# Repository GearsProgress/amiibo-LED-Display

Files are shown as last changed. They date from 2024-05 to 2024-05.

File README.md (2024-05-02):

# amiibo LED Display

This repository serves as documentation and storage for the UW-Stout Capstone project created by Dylan Robens, Austin Weber, Joaquin Sabin, and Alex Schroeder.

These files are provided as is and with no liability, however they are free to be used to recreate the project.

This repository is not meant to be a tutorial, but everything you would need to recreate the project should be documented. If you have any questions, feel free to reach out!



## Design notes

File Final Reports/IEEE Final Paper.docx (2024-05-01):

Joaquin Sabin, Dylan Robens, Austin Weber, Alex Schroeder, Member, IEEE

# I. INTRODUCTION

This project overviews the subject of Near Field Communication (NFC) by exploring the basics of how NFC communicates and transfers data. It also focuses on how to design a Near Field Communication antenna. The can communicate with passive NFC tags at a practical distance without any noise or excess data interfering with the communication. It then applies the antenna design work by fabricating a custom printed circuit board so that it can be used in the real world and tested in real world scenarios.

The method of showcasing that the antenna is working and functioning as intended is demonstrated with Nintendo’s amiibo figurines that will be used as the communication device for ensuring that the data transfer is working. amiibo are little figures from Nintendo that contain NFC chips (NTAG215) inside them. These chips store tons of data for multiple different games which makes them perfect candidates to see if the antenna is able to accurately transfer data at a fast rate.

# II. Design Problems and Objectives

The goal for the PCB design element of this project was to create a custom PCB with an integrated NFC antenna that is capable of longer-than-average-range data transfer and support power modularity with each antenna. The NFC readers will interface with a ATMega2560 microprocessor, common cathode multicolored LED lights, power supply, and power transfer nodes. All these elements, combined with a custom shelf-like housing designed and built using a 3D printer, can come together and create a display shelf that scans NFC based collectable figurines and changes the colors of the LED lights accordingly. This will have required multiple iterations of custom PCBs, custom programming, and many iterations of 3D modeling work.

The NFC based collectable figures being used are Nintendo’s amiibo. The reasoning behind using amiibo is for safety and security reasons. The antennas were not designed to enable the ability to collect private or secure data from other NFC chips, such as credit cards, key fobs, and security devices. The amiibo figurines feature an NTAG215 NFC chip that stores game data unique to each figure. This unique data will be used to determine what figure was being scanned, which will then be compared to a database that will return the correct color of lighting for that specific figure.

# III. Detailed Design Documentation

The project had started with some general ideas and took some time to finalize what exactly it will be. It was decided that creating a display case with the ability to scan figures while also displaying them in a unique way within the case would be a nice concept. The group agreed on this idea and wanted to figure out how to incorporate electrical engineering concepts into a project like this, and the group hadn’t made any custom PCBs without guidance before, so wanted to learn how. It was decided to go with a box design that can house 3 figures at once and is made up of white plastic with a gray outer shell. The main reasons for going for a two-tone design is that it is more visually appealing, and the gray PLA stops light diffusion easily compared to white PLA. This way light will bleed through where intended, and not bleed where it is not intended.

When a figure is scanned, it’s unique figure data from the NFC tag hidden inside of it will be used to light up an LED which has the same color scheme as the figure. There are many ways you can use NFC technology and data depending on the type of chip you are scanning and the application. The antenna will not be able to be used to scan credit card data and personal safety devices. This design choice was done to ensure the project cannot be used in any malicious ways. Showing corresponding LEDs lighting up was decided to be a simple and useful method of displaying to the user that the NFC data is being read. The easiest way to utilize NFC data communication will be to use a multicolor LED, and light it up according to the ID scanned. Between the 2 types of LED lights, (common cathode and a common anode) it was determined a common cathode would be the best to use as it will be easier to supply different voltages to the RGB LED.

The data from the amiibo will be read through wireless data transfer as long as it is within range of an NFC antenna. Researching how NFC antennas work was the main focus of the design from the first semester. The CLRC663 chip was decided to be the best use for the antenna as it is specifically for reading and processing data being received from an NFC antenna. Incorporating this chip into the custom PCB required a dive into the schematics of the chip to find out how the CLRC663 operates.

Early Conceptual Stages of the Custom PCB:

The project originally involved a single board with three built in NFC antennas to read data from the NFC chips that were placed on them. This was done for simplicity of manufacturing down the road, but led to being too risky for the project in its current state if the board resulted in not working.

The project was redone as a separate NFC antenna board, combined with a custom-made motherboard designed from Arduino Mega 2560 schematics. This was done to allow modularity for the final product and allow the ability to switch out multiple revisions of NFC antenna boards as new designs were made. Having this capability allowed easier access to testing designs as they came in and more adaptability down the road.

An RC522 chip was originally featured on the NFC antenna PCB but later changed as the RC522 is no longer available. Later this was switched out to the CLRC663 due to part availability and future compatibility with other components. Due this chip being relatively new, public documentation, code, and forum posts were not widely available and led to project delays that affected the end product.

Antenna Design Calculations:

After figuring out the design and goals of the project, the next step was to decide on the layout of the antenna PCB. The first step was the general layout. To achieve this, a few days were spent specifying the parameters of the antenna. It was important to know what needed to be scanned in the first place. To get data transferred from the NFC tag to the NFC antenna it was important to know what frequency the NFC tag from the amiibo figure could operate at. Datasheets showed that the figure has an NTAG215 chip inside of it which is able to transfer data at a frequency of 13.56Mhz.

After some research it could be found that an ST25TB or ST25TV series antenna had the required tuning frequency necessary for communicating at 13.56Mhz. Initially it seemed that either the ST25TV or ST25TB could be used but further research showed that the ST25TV series would not work with the NTAG215 chip found in the amiibo figures. From here it was decided to go with the ST25TB series antenna. This provided a great starting point for beginning the antenna calculations.

Deciding on the Shape of the Antenna:

Early design revisions of the NFC antenna board featured multiple versions with different antenna shapes. Research was done to determine the most effective antenna shape for the purpose of the NFC Antenna. It was discovered that a circle design has less data loss, but the square design has more stability. It is for this reason that for the antenna design on the NFC antenna board, a square design with rounded edges was featured as the main antenna. This design incorporates features from both the circular and square design that gives us beneficial traits from both. This design was also chosen due to limitations during board development from the software that was primarily used to design said boards. The simplified geometry allowed for easier calculations of antenna properties during development and led to the development of an accurate Smith Chart to aid in the antenna tuning process down the line.

NFC Antenna Smith Chart

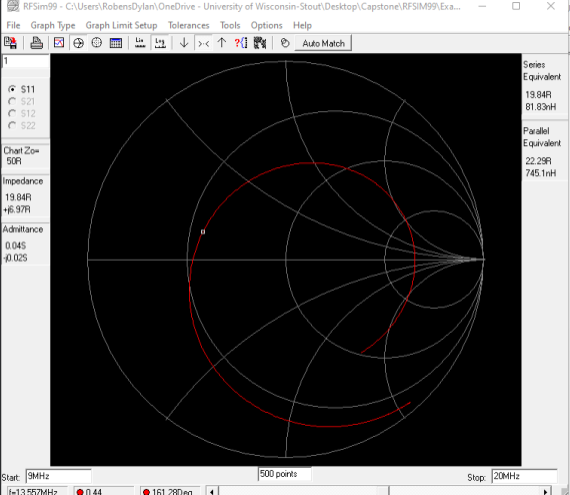
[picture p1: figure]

Finding The Ideal Operating Range/Distance:

NXP, an RFID/NFC antenna design company, features a simulation tool to find the ideal operating range that would be needed. It also provided useful documentation and made it possible to learn what kind of range the antenna could achieve. The notable details learned here were that a 4cm-diameter antenna would allow for an approximately 3cm operating range to scan the NFC tag.

Early Antenna Design Equations and Parameter Calculations:

After the operating range, the shape, and the size of the antenna had been decided, research began to find the necessary equations and information that would be needed in order to calculate the electronic components required for the antenna. Since the EMC filter used for the antenna was static, the matching circuit had to be tuned in the simulation to give the intended result. From here, the next step would be to decide on figuring out the actual antenna-specific values. Research showed that the internal resistance of the coil for the antenna could be found by taking the resistivity of copper, multiplying it by the length of the coil of wire, and dividing it by the cross-sectional area of the overall wire.

After calculating the resistance of the antenna, the inductance of the antenna could be found by using the number of turns, coupling coefficients, resistance of the antenna, and diameter. Once the inductance in the circuit was known it could then be used to find the capacitance. Next, the values were plugged into an online antenna calculator software which was used to double check that all the calculations were accurate and plausible.

NFC Antenna PCB Design:

The resulting design and schematic for the NFC antenna PCB was based on the supplier recommended circuit for the CLRC663 and conventional standards for NFC antenna circuits. 0-ohm resistors were utilized throughout the design to reduce EMI and achieve effective data transmission between the CLRC663 and the main processor unit on the custom motherboard. Additional test pins were added in the design to allow for additional debugging capabilities, should issues arise with the board.

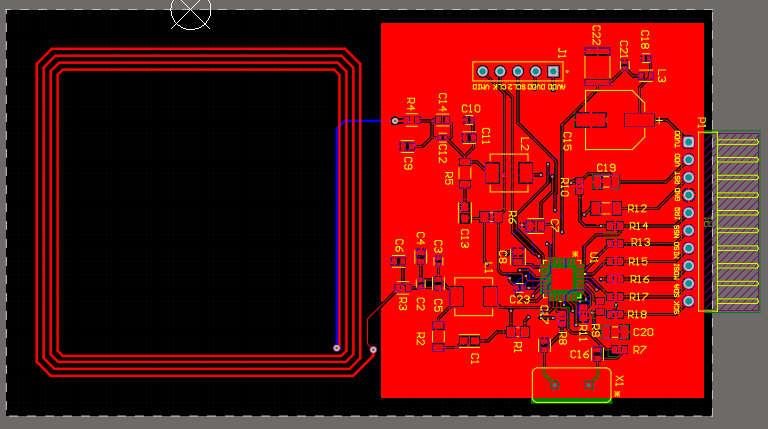
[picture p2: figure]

NFC Antenna Custom PCB Design Schematic

Custom Motherboard PCB Design:

In addition to the antenna, a custom motherboard would be needed to have the logic of the system running on it. It was designed and created using an open-source Arduino 2560 schematic as a reference, only including the aspects that would be relevant to this project’s needs. The main things that were changed about this board are the headers that are being used to interface with the NFC readers, LEDs, and various other electronic devices present within the final design. To reduce the cost of the system overall and increase the amount of available space, unused headers were removed when they were not needed for any devices in the system. The main reasons the custom motherboard was created and used in this project was due to the fact that it would allow for a better use of space and provide the additional memory required to store all the amiibo data. Using these custom boards were beneficial because they have the space efficiency of an Arduino Uno with the memory abilities of an Arduino Mega 2560.

PCB Fabrication

PCB fabrication was done by JLCPCB, a PCB manufacturing company based in China. It was decided that PCB assembly would be completed during the fabrication process, due to the pick and place capabilities that were featured at their facilities and the complex nature of the custom PCB designs. Due to the location of JLCPCB and miscommunication between the design team and the manufacturer, multiple project delays occurred that affected the end product. When globally sourcing the parts from different manufacturers, multiple shipping delays occurred that pushed the timeline of the project back further and led to less time to debug the boards.

This issue was primarily encountered when ordering the first PCB design, which was the NFC antenna board. After having first ordered the parts that would be required for the board, it took over a month for those parts to be shipped to the JLCPCB manufacturing site. This led to parts that were previously in stock at the manufacturing site being out by the time the previously ordered parts arrived. Due to this, many delays were experienced in receiving the NFC antenna boards and as a result there has been less time to test and debug. This issue was also experienced with the custom Arduino Mega Boards that were created, but to a lesser degree due to previous experience with the capabilities of JLCPCB’s stock options.

PCB Fabrication Results

After the custom NFC antenna boards were received, testing immediately began and early testing unfortunately showed that they do not operate as expected. Due to the limited open-source code that is available on the internet for the particular chipset that was used, the boards were not able to function as expected. It was found that its possible to read from the CLRC663 chip on the board. However, the registers from the chip are set with default 1’s and 0’s. In order to program the chip with its intended values, a Clev663BM Programming board would be required to import the program onto our chips. If there was more time to debug these boards and possibly rework the design itself, there could have been a better opportunity to make a immediately functioning board that works as the simulations show they should.

Another large issue was encountered with JLCPCB when the custom motherboard was ordered. JLCPCB incorrectly placed a lot of the IC’s and microchips that were present on the board due to the naming conventions that were used; the manufacturer incorrectly assumed that a lot of the parts had an orientation that did not matter. This led to the board not functioning as expected and being completely unusable with the project. If more time was available, more testing could be done to debug these boards and fix a multitude of the issues that are present.

3D Modeling

While the PCBs were being made in Altium, work also began on the necessary housing in which the NFC antennas would rest in. The plan was for the amiibo figures to have a visually appealing shelf-like housing, so they wouldn’t just be resting on a large PCB with a bunch of wires visible to the user.

The original prototype consisted of 11 individual files that would need to be printed to complete one full shelf. The general concept was that the amiibo were to be a slotted into the shelf and rest in place while lighting up LEDs that would correspond to the data being read from the amiibo. The shelf was also made to be easily constructable by hand without the need for any tools. This was to make disassembly faster in case a shelf had an issue. The shelf parts slid on and off easily and constrained the shelf in a physically secure way.

While printing, some of the parts were extremely thin, which led to warping issues for longer prints. This caused many prints to fail in early design stages. Originally the project was utilizing a personal 3D printer to print the needed parts, but this constrained the timeframe of the project as the prints were inconsistent and took quite a while to print. The group was later informed about the printing lab on campus and all 3D printed parts for capstone were supposed to be printed in the lab. The prints had been changed to be made easier by the time the printing restrictions were introduced, so the design had been refined by removing redundant parts and making existing parts more robust to avoid warping. While printing, the group also encountered some issues with removing supports in very tightly cramped places, so the files were changed to remove any instance that would create supports that were troubling to remove.

The second prototype featured a slot for a photo resistor to activate/deactivate an NFC antenna and a slot for the NFC antenna boards to rest under where the amiibo would sit. After designing this prototype, the final design was fabricated at the print lab and the design was constructed. Testing began after the final design was constructed to test out the capabilities of the NFC antennas in conjunction with the Arduino Mega as well as making sure that everything was functioning as expected. During this phase, minor design adjustments were made to increase the efficiency of the system and ensure that it was as “end-user proof” as possible.

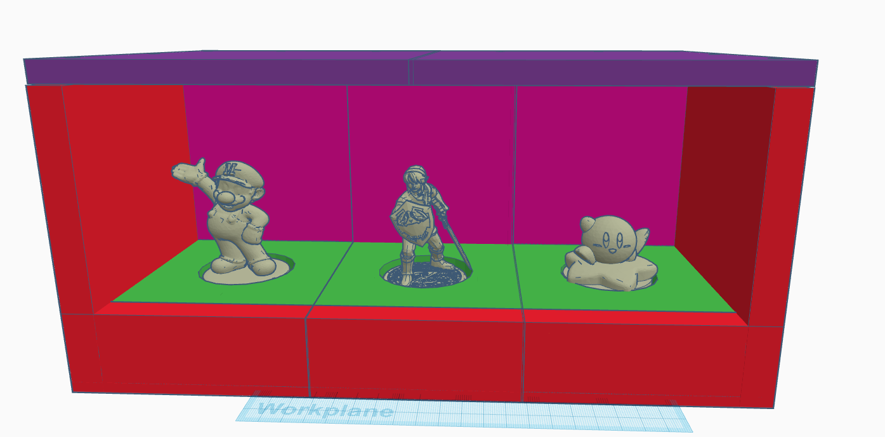
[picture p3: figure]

Arduino Software

During the planning stages for the software, it was determined that storage space would be an issue due to the large number of figurines the software needed to be compatible with. It was also determined early on that an Arduino-based motherboard would be used for the microcontroller to control this entire project, as this was a device that the team had familiarity with. The storage needs required the use of an Arduino Mega, which contains enough storage space for the head, tail, and color values of each figure.

A goal of the software was to split each sensor into its own class. That way, each sensor could be individually tested to make sure it was functioning properly. The program utilizes three main classes: one for the MFRC522 board, one for the photoresistors, and one for the LED logic. The MFRC522 and LED lights that were purchased both had recommended libraries for interacting with them, which assisted in the programming process. This meant that the focus could be on new aspects of the program, rather than learning how each external device functioned. The photoresistor class was custom made, and although simple, was extremely helpful in making the code clean and concise.

The main loop that runs the device checks each photoresistor to see if one has dropped below a light threshold determined on startup, which means a figure has been placed inside of a slot. If true, the NFC board will read the figure, take the received data, and search for a match within the database. It returns the match and changes the LED lights accordingly. Once a figure has been placed, the program checks if the photoresistor exceeds a preset threshold. If it has, then a figure has been removed from a slot. The program then turns off the respective lights and waits for a new figure to be placed.

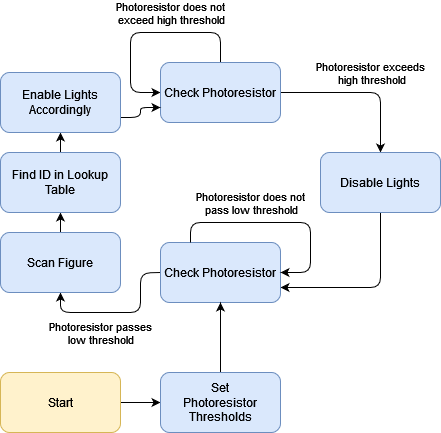
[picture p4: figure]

# IV. Safety

When it came to safety in the design, the goal was to provide as few points as possible for an individual to interact with the electronics in the project. A shroud was designed for the electronics that allowed for the antenna to still scan the NFC chip that was placed close to the antenna. That way, the optimum functionality of the device was maintained while reducing the amount of risk that the user would experience. The plan was for the user to never be able to interact with the wiring, and give a sort of “magical” feeling when placing and removing the figurines.

In terms of the antenna design itself, the antenna was designed so that it would only operate at a specific frequency of 13.56 MHz. which would remove the ability for the antenna to scan other chips that weren’t operating at the same frequency and therefore prevent the ability to steal data that the system isn’t designed for.

# V. ETHICAL CONSIDERATION

Although the system poses no danger or ethical concerns to people, it does interact with a piece of proprietary technology created by a multi-billion-dollar company. It is very important that the project does not infringe on any copyright or trademark by Nintendo and its subsidiaries. This only applies to the code created to interact with the amiibo figures, which are distributed by Nintendo. Much of the amiibo data is not encrypted, including the 2 “pages” (four bytes each) of data used by the program. However, pages 40 to 130 are encrypted by a private data key owned by Nintendo and is not released to the public. Using this key would directly be a violation of Nintendo’s copyright and could cause legal trouble. Thus, the project does not violate ethical codes as it does not use this data key.

The project also makes use of multiple open-source libraries and programs throughout. Some of these libraries, such as the NFC library, were completely free to use and redistribute. Other libraries, such as Adafruit’s NeoPixel, was free to use but cannot be redistributed. That means that the final program would be undistributable without it also being open source. This is not an issue as the program was designed to be open source.

# V. Conclusion

This project introduced many concepts of antenna design, PCB design, and 3D modeling. A lot of information was learned about these topics that had only been briefly touched upon in previous college courses taken by the team.

For the antenna design, the key concepts learned were that there are many things that go into designing filters for the data, as well as determining proper dimensions of the antenna to reach the preferred range requirements. In addition to that, this project also taught quite a bit about antenna parameters, specifically how different shapes of the antenna coil would affect the readability and quality of the data being received.

The other major conclusion that could be made from designing the antenna is how the size reflects field strength. Notably, the number of turns in the antenna are directly proportional to the field strength of the antenna. It was decided that having multiple turns and a larger diameter antenna would have a field strength that would reach out 3cm from the board.

After having finished the antenna design and implementing it on a PCB, a lot has been learned about the design process behind these antennas and how to effectively test a design to make sure it works. Through the experience using RFSIM99 and the circuit simulation represented by a Smith Chart, the effectiveness and importance of simulating design work to ensure a working outcome was discovered. If there had been more time, resources available, and not issues from JLCPCBs fabrication process, the PCB would have been implemented and working as intended, however the clrc663 chip was not programed, and we did not have a developer board to program the board in time.

The actual software design aspect of the PCB went smoothly. Prior experience from college courses and internships from the team allowed for confidence using Altium Designer to create the PCBs and Visual Studio Code to create the software. Once the design was fabricated, the issues arose with the fabrication company, JLCPCB. They did not have the parts that were present within the design, meaning a lot of the components had to be globally sourced from other companies around the world. After a back-and-forth communication mess that went on for about a month and a half, the boards were finally ready to be ordered and fabricated. This whole ordeal increased production time and delayed the project well beyond the dates that were originally expecting and reduced the amount of time overall that was spent with the custom boards. As mentioned previously, JLCPCB also incorrectly placed some of the parts due to naming convention issues which unfortunately make the custom motherboard completely unusable.

Lastly, the 3D printed model was very educational when it comes to mechanical and physical design engineering. Multiple different iterations were gone through to reduce supports, increase structural strength, and seamlessly transition between pieces of the casing. Space tolerances needed to be accounted for to maximize the amount of usable space while making the shelf not extremely huge and bulky. The walls were needed to be designed in a way that could support various loads, allow light passthrough, and feature baseplates that would be thin enough to allow data transfer between the NFC antennas and chips.

# VI. References

[1] NXP. “Training - Mobileknowledge.” NFC Reader Design: How to Build Your Own Reader, Feb. 2015, www.themobileknowledge.com/wp-content/uploads/2017/05/NFC-Reader-Design-How-to-build-your-own-reader.pdf.
[2] NXP. “NFC Reader Design 2 - Antenna Design Considerations.” NFC Reader Design 2 - Antenna Design Considerations | NXP Semiconductors, 13 Oct. 2016, www.nxp.com/video/nfc-reader-design-2-antenna-design-considerations:DESIGN-NFC-APPLICATIONS.
[3] Affendi1, N. A. M., and M. Amirruddin1. “IOPscience.” Journal of Physics: Conference Series, IOP Publishing, 1 May 2021, https://iopscience.iop.org/article/10.1088/1742-6596/1878/1/012024/pdf
[4] NTAG213/215/216 NFC Forum Type 2 TAG Compliant IC with 144/504/888 ..., June 2015, www.nxp.com/docs/en/data-sheet/NTAG213_215_216.pdf
[5] Phillips Semiconductors. “13.56 MHz RFID Proximity Antennas .” BAS, 8 Nov. 2002, nic.vajn.icu/PDF/nfc/Mifare/Mifare_13.56_MHz_RFID_Proximity_Antennas.pdf
[6] Merz, Christian. “Impedance Matching for NFC Applications.” EE Times Europe, 7 Jan. 2022, www.eetimes.eu/impedance-matching-for-nfc-applications/
[7] easyELAB. “How RFID Works? And How to Design RFID Chips?” YouTube, YouTube, 21 Dec. 2018, www.youtube.com/watch?v=FwbWvjq_iiM
[8] Ham Radio Guy - G0KSC. “How to Model Antennas with 4NEC2 Antenna Modelling Software - Part 1, the Basics.” YouTube, YouTube, 30 Nov. 2020, www.youtube.com/watch?v=W2N8AeOFqaM
[9] Merz, Christian. “Impedance Matching for NFC Applications: Part 2.” EE Times Europe, 16 Dec. 2021, www.eetimes.eu/impedance-matching-for-nfc-applications-part-2/
[10] Merz, Christan. “Impedance Matching for near Field Communication Applications.”, 10 Dec. 2020, www.we-online.com/catalog/media/o207264v410%20ANP084a%20EN.pdf
[11] NXP. High Performance Multi-Protocol NFC Frontend CLRC663 and CLRC663 Plus, July 2021, www.nxp.com/docs/en/data-sheet/CLRC663.pdf
[12] NXP. AN11019 “CLRC663, MFRC630, MFRC631, SLRC610 Antenna Design Guide.” 18 June 2018, www.nxp.com/docs/en/application-note/AN11019.pdf
[13] NXP. AN11145 CLRC663, MFRC631, MFRC 630, SLRC610 Low Power Card Detection, May 2015, www.nxp.com/docs/en/application-note/AN11145.pdf
[14] Barksdale, David. “Rfidbadge.” GitHub, github.com/amatus/rfidbadge/blob/master/CLRC663.cpp. Accessed 12 Dec. 2023.
[15] OSSLibraries, Rotzbu. “Osslibraries/Arduino_mfrc522v2.” GitHub, 17 Oct. 2020, github.com/OSSLibraries/Arduino_MFRC522v2

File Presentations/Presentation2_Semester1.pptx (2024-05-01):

## NFC Antenna & PCB Design

Joaquin Sabin
Austin Weber
Dylan Robens
Alex Schroeder

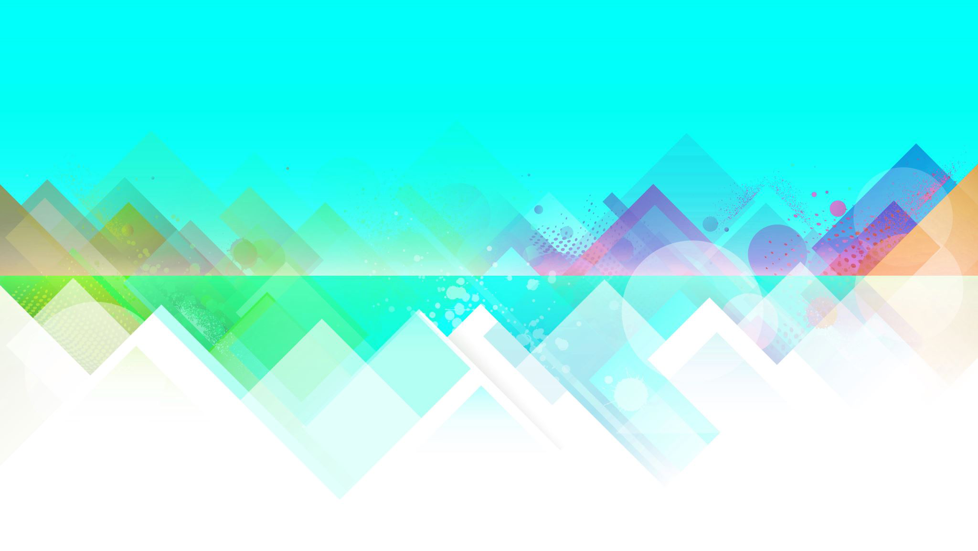
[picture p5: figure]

## Project Overview

We are designing and creating our own Near-Field Communication (NFC) antenna which is based on the same technology as RFID. We are going to integrate 3 of these antennas into a custom PCB which will be controlled via a microcontroller. (Complete by first semester)
We will then have a second microcontroller hooked up to the 3 antennas which will be able to process and interact with NFC chips. Based on the NFC data being received, the microcontroller will output a command to the rest of the circuit.
We plan to house our PCB in a shelf to be used to display amiibo figures.

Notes: Joaquin

## Gantt Chart

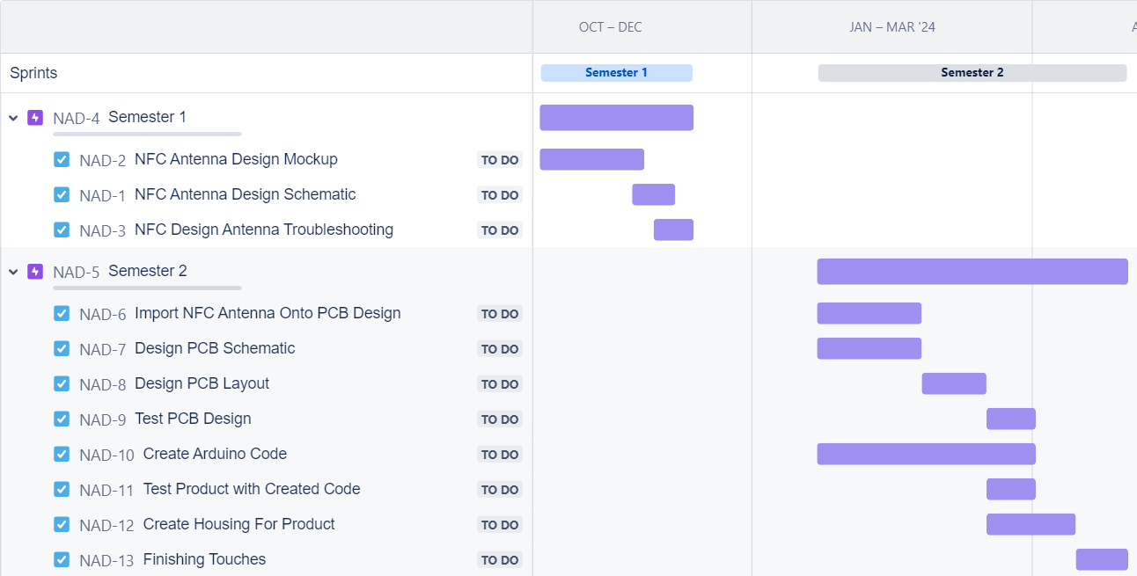
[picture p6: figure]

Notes: Alex

Fall Semester
Research NFC properties
Selecting and calculating parameters for the Low pass filter present on the antenna
Calculating the matching circuit present with the antenna
Calculate NFC antenna parameters
Calculating the resistance, inductance, and capacitance of the antenna
Design and simulate NFC antenna
Using RFSim99, to get an accurate reading of how our created antenna will operate

Spring Semester
Create custom PCB with embedded NFC antenna and power sharing
Importing our antenna design onto our custom-made board
Test/debug PCB
Testing to see if our components are behaving as expected
Program PCB logic
Creating code from scratch to utilize the data we will be scanning with the antenna
Design shelf/housing in CAD
Build case/shelf and assemble project

## Member Roles

Dylan
Antenna design research
3D Modeling
PCB Design Layout
Arduino Programming
NFC reader and chip interface protocol research
Alex
Antenna Design Research
Antenna Simulation
PCB Layout Design
PCB Schematic Design
Joaquin
Antenna Design Research
Antenna Simulation
PCB Logic Design
3D Modeling
Austin
Antenna design research
NFC215 chip data structure and storage
Arduino programming
NFC reader and chip interface protocol research

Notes: Dylan
Everyone is doing design research for the antenna. It’s the main focus of our capstone project currently and we want to ensure that we nail the design of the antenna down.
Alex and Joaqin plan on doing Antenna simulation to ensure that our Antenna design is working as intended in theory.
Meanwhile Dylan and Austin will do NFC reader and chip interface protocol research

Second Semseter:
Alex, Dylan, and Joaqin will all be working on the PCB Layout and Logic design as we want to square away the PCB design early on
Austin will be working on the NFC 215 Chip Data structure and storage while this is going on.
Austin and Dylan will work on Arduino programming so that our custom pcb will work as intended once we receive it, and that way we can hopefully start testing as soon as we get it.
Dylan and Joaquin plan on doing 3d Modelling to house the PCB Semester 2 after the NFC Antenna is squared away

## Basics of How NFC Works

- RF Field
- Passive RFID tag operates at different frequency ranges
- HF: 13.56 MHz (Target frequency)
- RF Field Modulation
- Antenna design: Coiled Octagon
- Antenna induces a magnetic field
- NFC chip sends signal when current is induced

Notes: Dylan
NFC Antennas work by sending out an RF field that will oscillate at a designated frequency (Passive RFID Tags operate at different frequencies)
Passive RFID tag operation frequency ranges:
LF: 125-134 kHz
HF: 13.56 MHz (This is the target frequency we are hoping to achieve as this allows us to operate with what we need)
UHF: 856-960 MHz
The NFC antenna will modulate its own RF field to send commands through its antenna
The antenna will be in the shape of a octagon which will be coiled with multiple turns in it
The antenna will induce a magnetic field, this magnetic field will induce a current within the receiving NFC chip
NFC chip will be powered on when a current is induced and modifies the RF field which the Antenna will detect.

## Background NFC Information

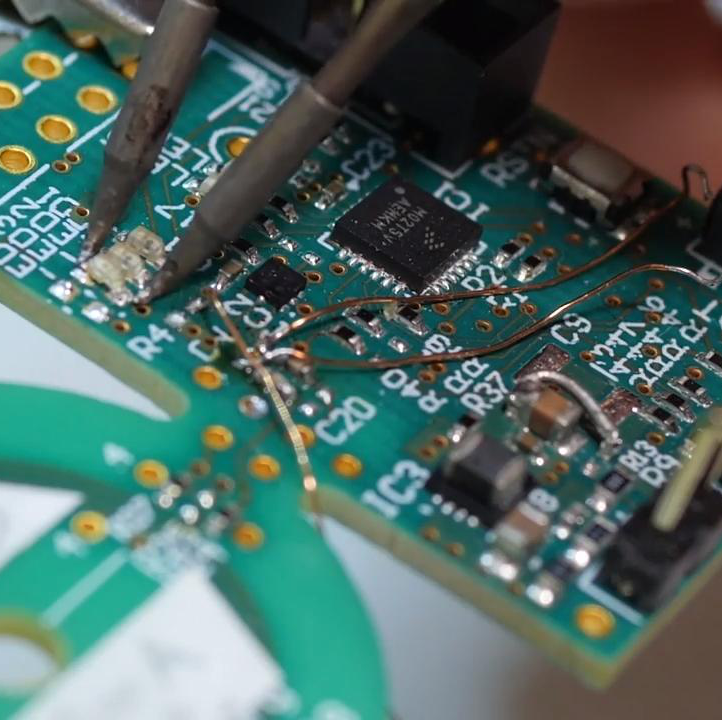
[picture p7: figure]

- NFC ISO 14443
- International standard for proximity chips/cards used in Identification and Transmission protocols
- 14443-2 is for Radio frequency and Signal Interfacing
- Two types of NFC Antennas: A & B
- Communicate at 13.56 MHz
- Modulation and Initialization are the only differences.
- Radius is proportional to reading field distance
- We have decided upon 14443-2 Type A for our design.

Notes: Alex

Our selected antenna will have a microprocessor that uses the NFC ISO 14443
International standard for proximity chips/cards used in identification and transmission protocols
Specific standard we selected is used for radio for radio frequency and signal interfacing
Two types of NFC microprocessors that we could have selected, A & B
Both communicate at 13.56 MHz and we have to create an antenna that operates at that frequency
Between these two standards, modulation and initialization are the only differences
The radius of the antenna itself is directly proportional to the maximum distance at which the antenna can scan for signals
Based on all of these factors, we chose a 13334-2 type A microprocessor for our antenna design

## Antenna Design

  - Circular Vs Square Loop Antenna Design
  - Both have fields primarily determined by thickness of gap between antenna coils, the radius of the loop, and the number of turns
  - The square shape has more stability while the circle has less data loss
  - Overall, we decided to go with a hybrid approach and create an octagon-shaped antenna. We will roughly have the stability of a square with the losses of a circle

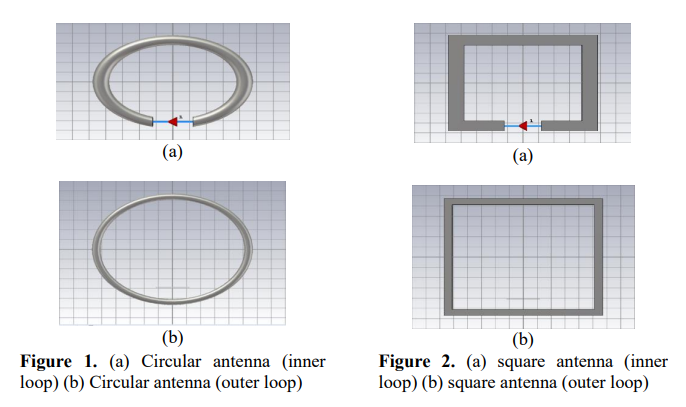
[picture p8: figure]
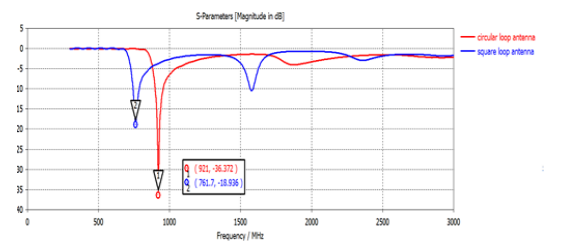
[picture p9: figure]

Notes: Joaquin

## Antenna Design Cont.

- Field Strength directly proportional to Radius/Diameter
- Larger Diameter => Larger field strength
- Smaller Diameter => Smaller field strength
- We need a smaller antenna so we can fit a limit-switch/button into the system so it can scan only when set down.
- We are aiming for a 4cm diameter antenna which will give us a ~3cm field range

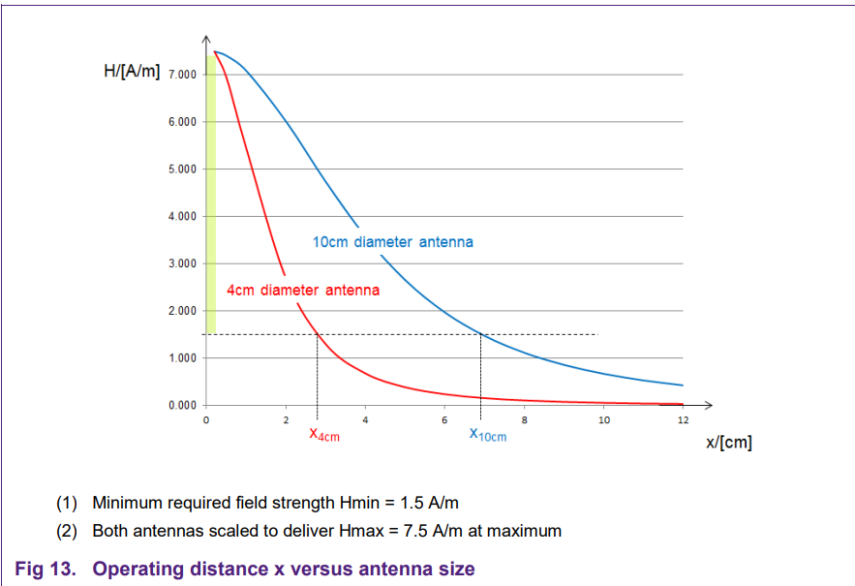
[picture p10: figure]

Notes: Joaquin

## Antenna Design Equations:

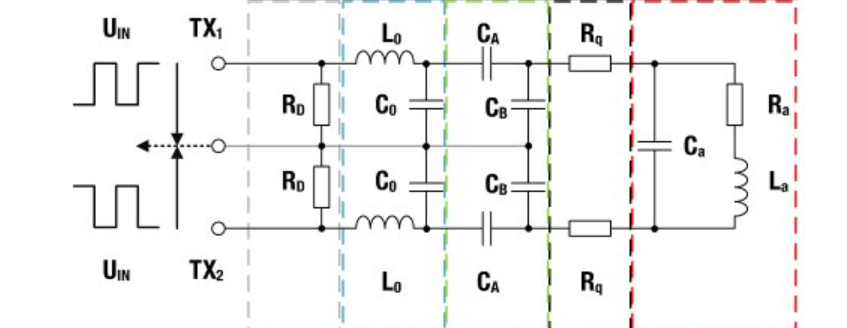
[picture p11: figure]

- Need to know Inductance, Capacitance, and Resistance of components for our NFC Antenna
- EMC Filter values are decided to reach Cut Off Frequency we desire.
- Cut Off Frequency calculated with the Inductance and Capacitance of the EMC Filter.
- Need to find out Capacitance A and Capacitance B for the Matching circuit.(Formula on right) ->
- Capacitance is dependent upon EMC Filter variables
- Once we figure out the matching circuit values, we can calculate what the output of our entire circuit will be.

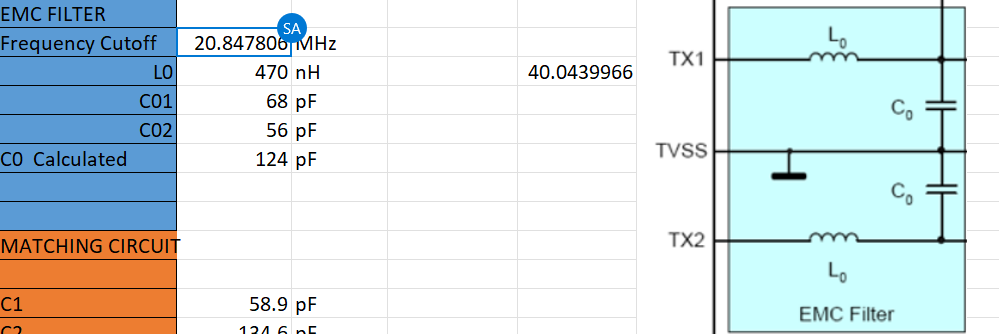
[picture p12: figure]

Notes: Alex:
Need to know Inductance, Capacitance, and Resistance of components for our NFC Antenna
Multiple parts to the antenna design:
EMC Filter, Matching circuit, Antenna Circuit

EMC Filter values are decided to reach Cut Off Frequency we desire.
Cut Off Frequency calculated with the Inductance and Capacitance of the EMC Filter.

Dylan:
Matching circuit has capacitance values that are dependent upon the EMC Filter
For our matching circuit we need to find out Capacitance A and Capacitance B
Once we figure out the Matching Circuit values we can Calculate the Antenna circuit values

## The NTAG215 Chip

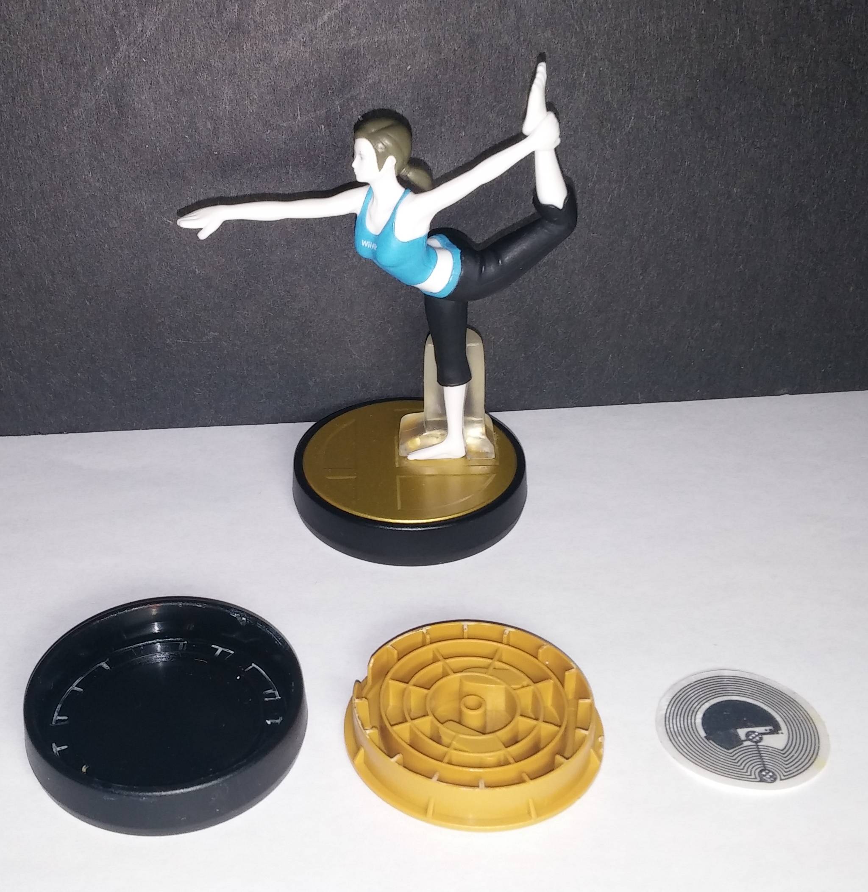
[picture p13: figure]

- Very common NFC chip
- This is what we are actually reading data from
- It is a tiny chip stored inside of the Amiibo figures (shown to the right)

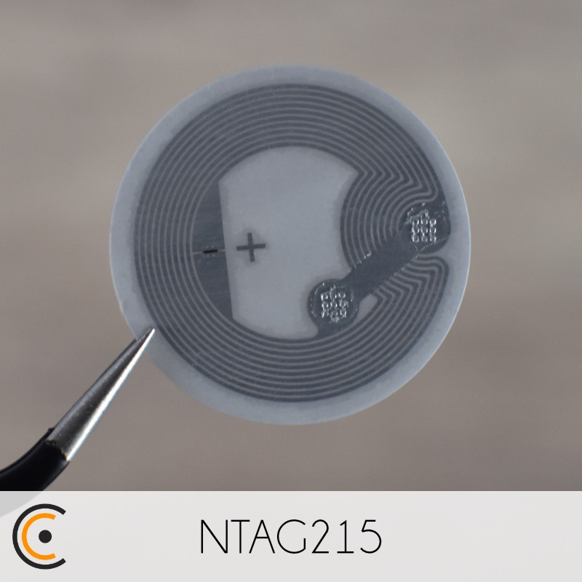
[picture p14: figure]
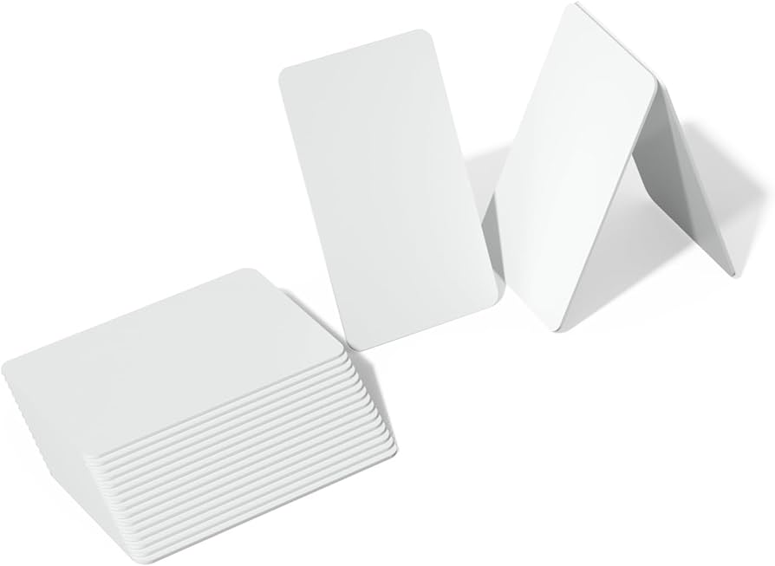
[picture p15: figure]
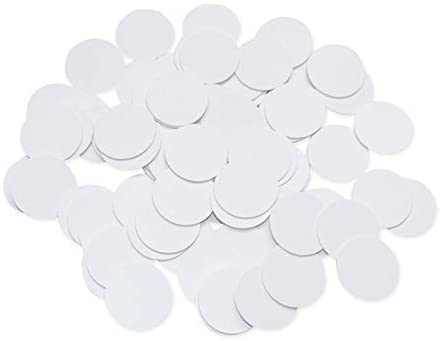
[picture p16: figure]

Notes: Austin

## NTAG215 Data Information

- 540 Bytes of EEPROM, 504 of which are available for user data
- Transfer rate of 106 kbit/s
  - Total transfer can be completed in 40ms
- Memory is stored in 4-byte chunks known as “pages”
  - Total of 135 pages
- 7-byte serial number that is set at the factory
  - +2 checksum bytes
- Lock bytes which specify pages that cannot be written to

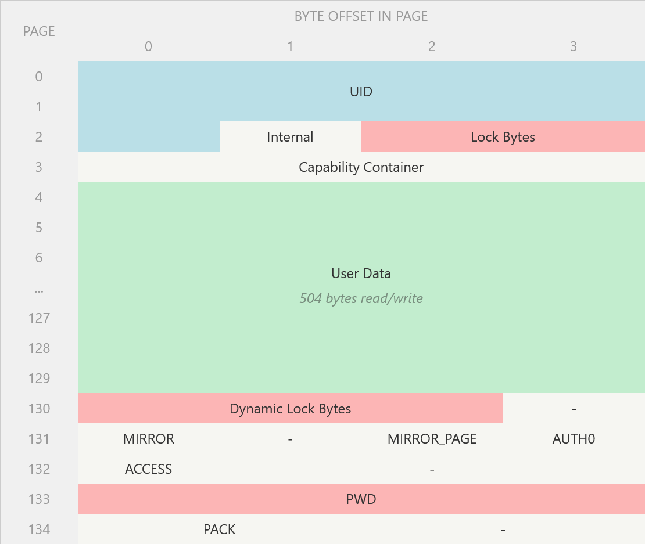
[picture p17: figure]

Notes: Austin

## Amiibo Specific Information

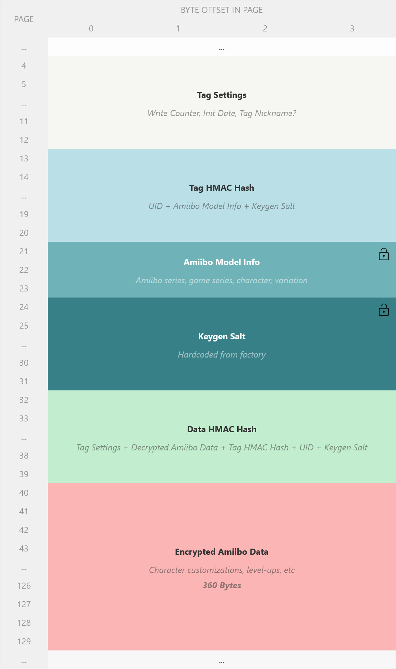
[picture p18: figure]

Amiibo Model Type
This is the important data for what we want to do
It is not encrypted, however it is locked
Located at pages 21 and 22
Encrypted Amiibo Data
360 bytes total
Requires a copywritten encryption key
Not legally obtainable

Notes: Austin

## Parts

- 3x NFC Reader (https://www.amazon.com/SunFounder-Mifare-Reader-Arduino-Raspberry/dp/B07KGBJ9VG)
- 1x Arduino Mega (https://www.amazon.com/ELEGOO-ATmega2560-ATMEGA16U2-Projects-Compliant/dp/B01H4ZLZLQ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)
- 1x Multi-Color LED (https://www.amazon.com/dp/B01C19ENDM/ref=twister_B01CNY3FY8?_encoding=UTF8&th=1) COMMON CATHODE
- 1x White Filament (https://www.amazon.com/Filament-Diameter-Tolerance-Printing-MIKA3D/dp/B0B5GWJY2H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)
- 4x Custom PCB board

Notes: Alex

Above are the parts that we selected that will be used for primarily testing in the future
We selected these to best replicate the PCB that we will be creating in the future
Having these components ahead of time will allow other areas to have active development simultaneously
Also purchased white filament for 3D Printing, selected this based on what we want our final color to be
We have a goal to purchase 4 custom PCB boards at the end of this project, pending how much each board will cost

## Design Challenges

- Researched around RC522
- CLRC663 is now being used
  - CLRC663 is a newer chip
- Simulation software difficulties

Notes: Dylan
We researched and planned to use the RC522 chip but learned that it is mostly obsolete now- and is no longer in stock. We then had to restart our research and decided to go with the CLRC663 chip instead as it is the newest chip.
Due to the CLRC 663 being newer, it can support updated technologies but has less documentation and libraries
Finding a simulation software for NFC antennas has been difficult, but we have a few resources we can use. Although we still have to do all the calculations as well as how to use any software we found.

## Questions?

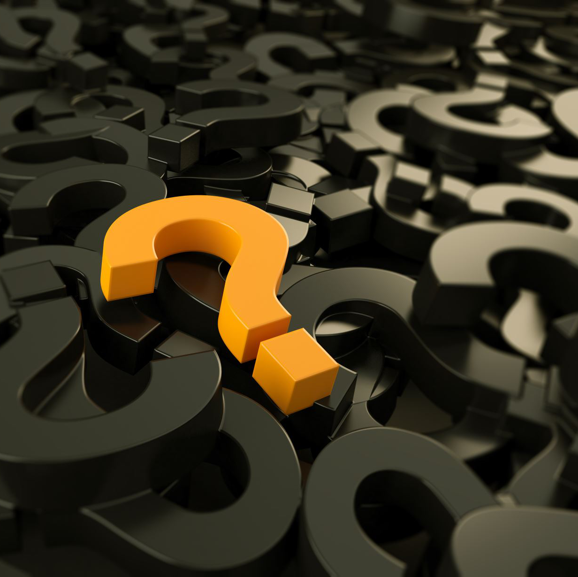
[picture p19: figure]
Yellow question mark

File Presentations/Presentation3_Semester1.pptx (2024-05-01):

## NFC Antenna design

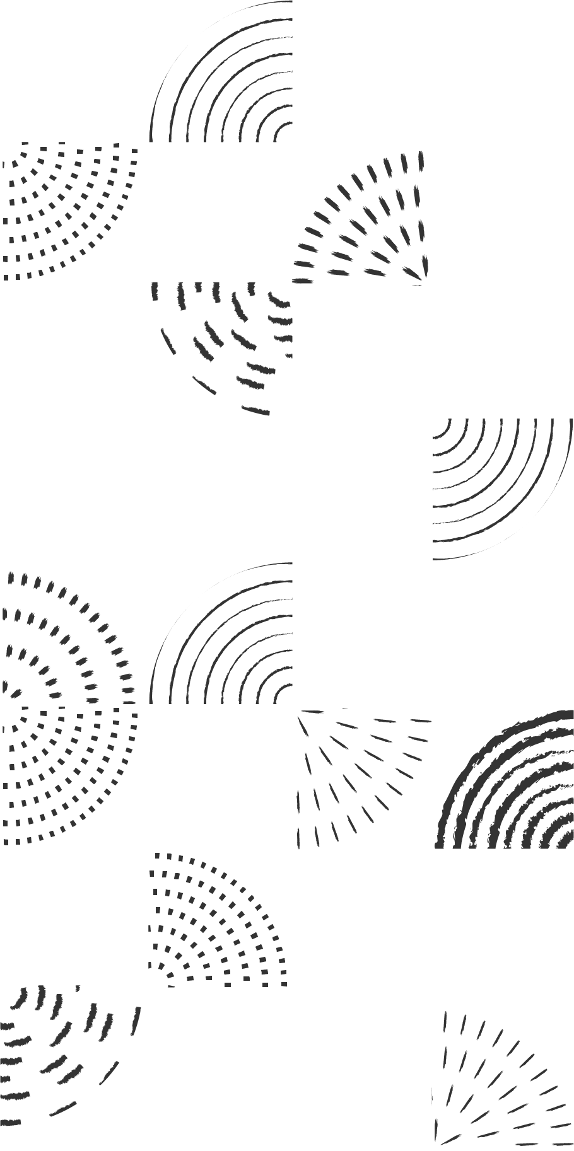
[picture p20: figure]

By:
Dylan Robens, Austin Weber,
Joaquin Sabin, Alex Shroeder

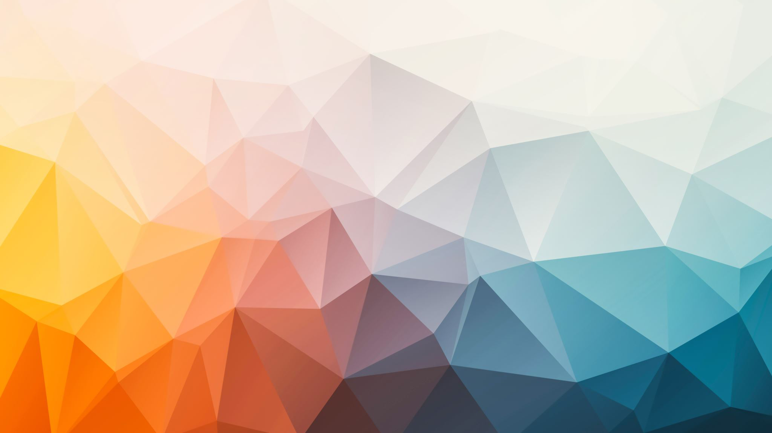
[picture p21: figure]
Triangular abstract background

## Project Overview

Design and Create NFC antenna PCB
Integrate Antenna PCB with a microcontroller on the same board.
Integrated board will be able to process and interpret all data received
NFC antenna will be to scan all Passive RFID NFC chips.
Interface with Amiibo?

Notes: Dylan
We are designing and creating our own Near-Field Communication (NFC) antenna which is based on the same technology as RFID. We are going to integrate 3 of these antennas into a custom PCB which will be controlled via a microcontroller. (Complete by first semester)

We will then have a second microcontroller hooked up to the 3 antennas which will be able to process and interact with NFC chips. Based on the NFC data being received, the microcontroller will output a command to the rest of the circuit.
We plan to house our PCB in a shelf to be used to display amiibo figures
Our Antenna will be able to scan all types of Passive RFID NFC Chips present as they operate at 13.56 MHz
We plan on using Amiibo at the moment to test multiple NFC antennas at the same time as they all have pre-filled data in their chips that is unique. We could very easily switch over to cards like our stout cards, or building keys

## Roles

Alex Schroeder – PCB Design, Testing, Final Report
Austin Weber - Code Design, Testing, Final Report
Dylan Robens - Code Design, Shroud Creation, Final Report
Joaquin Sabin – PCB Design, Shroud Creation, Final Report

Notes: Austin

## Gantt Chart

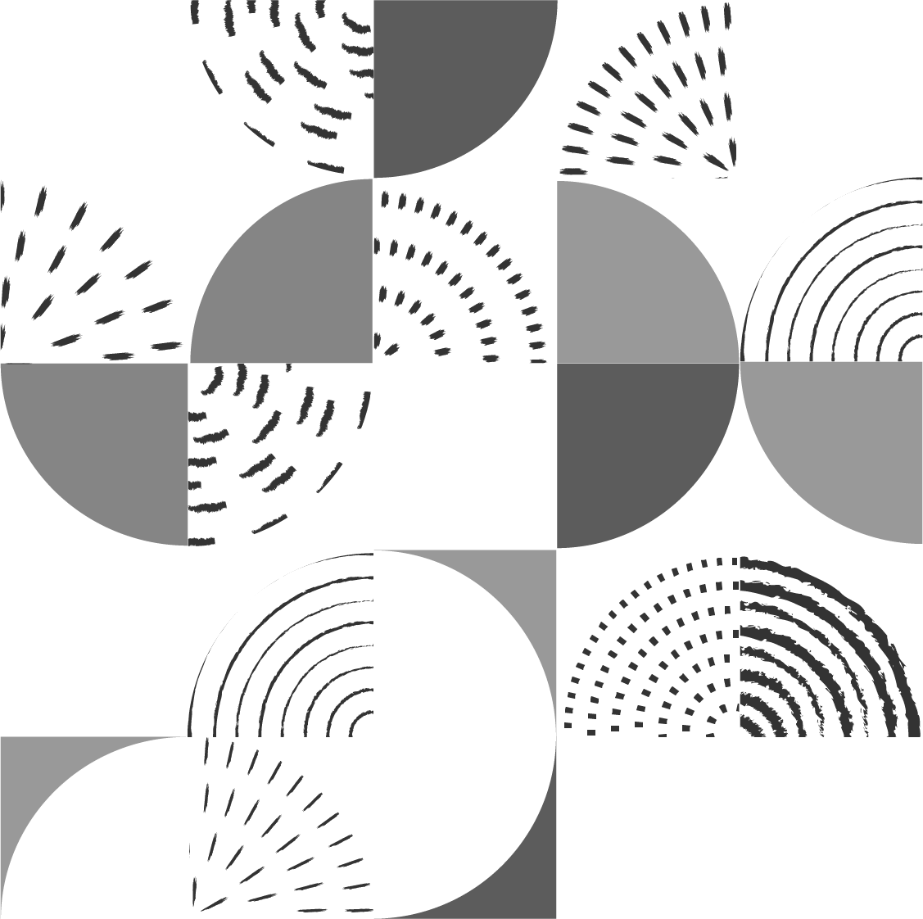
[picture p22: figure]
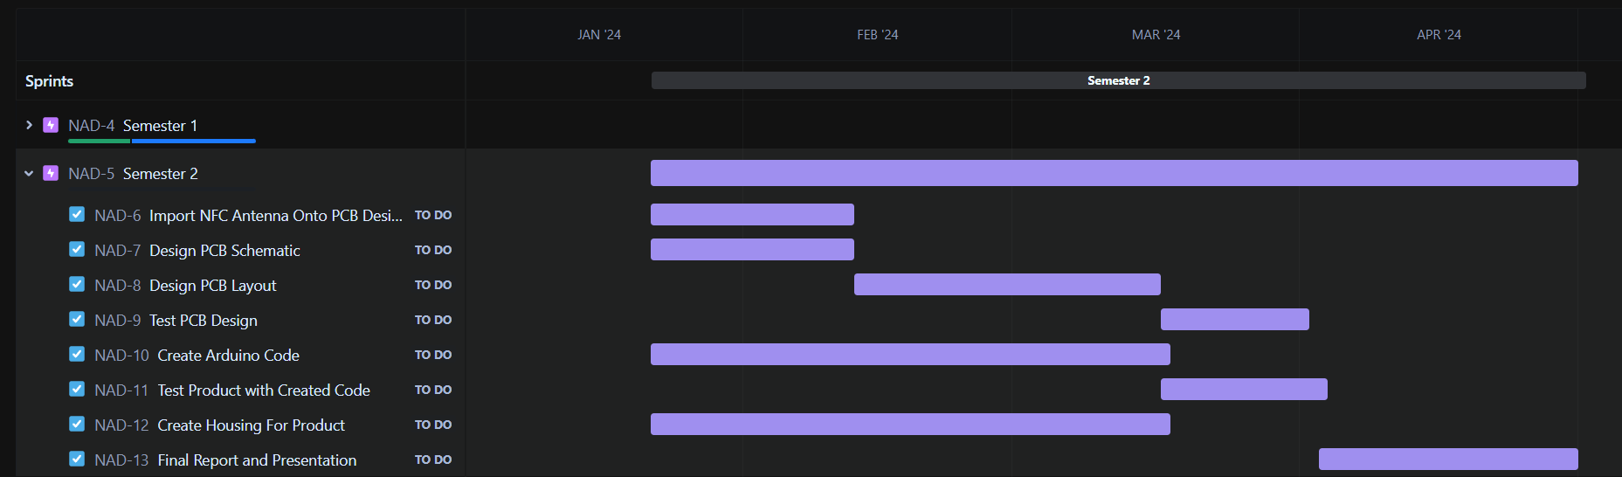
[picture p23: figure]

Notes: Joaquin

## Background Research

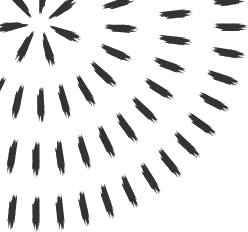
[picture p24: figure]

- Basics of NFC Communication and how it works
- Calculating Components
- NXP Antenna documentation
- What Antenna shape is most effective for NFC


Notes: NFC stands for Near Field Communication. It works by using a coil to induce a short range electromagnetic field that, when a passive RFID chip is brought into range of the Antenna’s field, will induce a current within the chip and thus power the chip which will allow for data transfer.
We dug through multiple NXP documents. NXP is a company that has multiple documents outlining the design process and decisions you have to make while designing an NFC antenna
NXP outlines how to calculate most components
Did some in-depth research on what Antenna shape was best for NFC antennas and learned about the direct proportionality of the diameter and the strength of the field.

## Antenna Design


- Designed the antenna in Altium Designer
- All antenna components were calculated through background research
- Used a program called RFSim99 to validate research results
- Achieved an optimum antenna design through simulating the equivalent circuit of our antenna


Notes: Dylan
Since last time we have presented we have finalized our antenna component values
We have tested our antenna via an RFSim 99 simulation, and with that we were able to conclude that with our current component values, our Antenna design will work when we go to test it and ensure that its worked.
The Antenna design has also been constructed within Altium designer
What's next for us is that we need to order a PCB to test if our Antenna design.

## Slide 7


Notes: Austin

## Part Selection


- Antenna test board – allows us to verify that our design works
- Four PCBs for the final design – complete with the finished antenna circuit integrated with an Arduino Mega chip (ATmega2560)
- 3D printed shroud to house the electrical components

## Plan for next semester

Receive our custom PCB
Integrate it with our Arduino Mega
Complete the Arduino Mega program
Design the final PCB with Arduino integration
Send in the final PCB for manufacturing
3D model and print final PCB housing

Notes: Joaquin

## Tests

EMF testing of the antenna
CLRC663 chip testing through Arduino Mega
Read and Write tests of the CLRC663
General program ability testing

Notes: Austin

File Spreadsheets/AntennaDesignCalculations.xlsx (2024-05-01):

 |  |  |  |  |  |  |  |  | Formula: | XB1,2 = (Rs/(RL-Rs)) * (XL +- RL * sqrt((RL/Rs) + (XL^2 / Rs*RL) - 1)
ANTENNA |  |  | CENTI | MILLI | MICRO | MEGA | NANO | PICO
Target Frequency | 13.56 | MHz | 0.01 | 0.001 | 1e-06 | 1000000 | 1e-09 | 1e-12 | XB1,2 Table
Target Impedence | 20 | Ω |  |  |  |  |  |  |  | Variable | Value
Q Factor | 20 |  |  |  |  |  |  |  |  | Rs
Antenna Diameter (in center) | 40 | mm |  |  |  |  |  |  |  | RL
Expected Operating Distance | ~30 | mm |  |  |  |  |  |  |  | XL
Track Width | 0.5 | mm
Track Gap | 0.5 | mm
ω | 85199992.77
N turns | 4
p avg | 0.08045977011 | mm
d avg | 43.5 | mm
u Naught | 1.257e-06
Inductance | 2.046747608e-06 | 2.05 | Micro Henries |  | ω0
Resistance | 0.7160914286
Capacitance | 6.730643574e-11 | 0.673 | Pico farads |  |  |  |  |  | Solution: | XB1 = | #DIV/0!
Permability of Copper | 1.256629e-06
Coil Cross Sectional Area | 354 | mm^2
Trace width | 0.5 | mm
Coil Length | 708 | mm
k1 | 2.34
k2 | 2.75
Area of Trace Face | 1.75e-08 | m^2
Resistivity of Copper | 1.77e-08 | ohm-meter
 |  |  |  | 40.0439966
EMC FILTER |  |  |  |  |  |  |  |  |  | X_A1,2 | -1.6
Frequency Cutoff | 20.84780615 | MHz |  |  |  |  |  |  |  | X_S | 1
L0 | 470 | nH |  |  |  |  |  |  |  | X_B1, 2 | 1
C01 | 68 | pF |  |  |  |  |  |  |  | R_L | 1
C02 | 56 | pF |  |  |  |  |  |  |  | X_L | 1
C0 Calculated | 124 | pF
MATCHING CIRCUIT
C1 | 58.9 | pF
C2 | 134.6 | pF

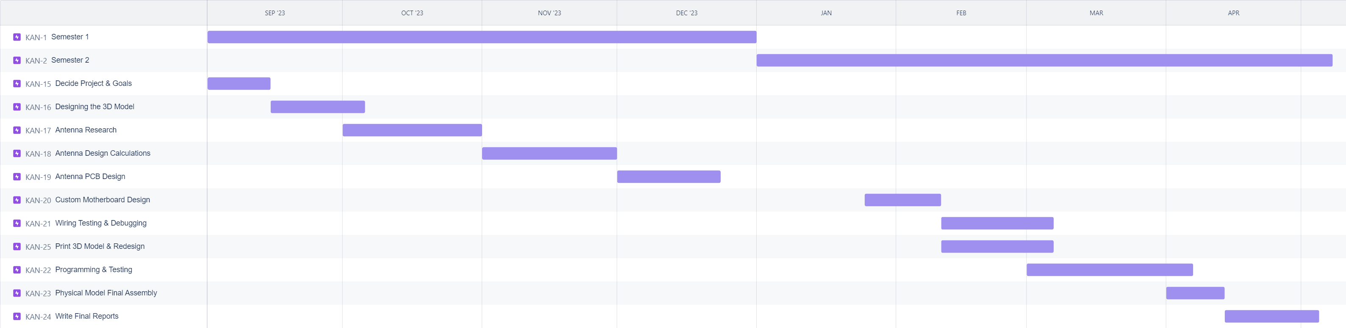
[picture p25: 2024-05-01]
Final Reports/GanttChart.png

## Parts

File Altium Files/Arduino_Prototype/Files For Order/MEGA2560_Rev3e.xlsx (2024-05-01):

Name | Description | Designator
1-1571563-4 | Pushbutton 6x6 Smd - White | RESET
1N4007 | 1.0A 40V SURFACE MOUNT GLASS PASSIVATED RECTIFIER M7 | D1
AC0603FR-071ML | 1M 0603 | R1, R2
ATMEGA16U2-MUR | 8-bit Microcontroller with 16K Bytes of ISP Flash and USB Controller ATMEGA16U2-MUR | IC4
ATMEGA2560-16AU | 8-bit Microcontroller with 256K Bytes In-System Programmable Flash - ATMEGA2560-16AU | IC3
C0603C104J4RACTU | 100nF 0603 50V | C2, C3, C4, C5, C6, C7, C8, C9, C11, C12, C16
C0603C220G1GAC7867 | 22pF 0603 | C1, C14, C15
CAY16-102J4LF | 1K 064R | RN3, RN4
CAY16-103J4LF | 10K 064 R | RN5, RN1
CAY16-220J4LF | 22R 064R | RN2
CC0603KRX7R7BB105 | 1uF 0603 | C10, C13
CG0603MLC-05E | CG0603MLC-05E | Z1, Z2
CSTNE16M0V53C000R0 | 16Mhz - SMD | Y1
CV201210-100K | 10uH 0805 | L2
EEE-1EA470WP | 47uF | PC1, PC2
FC4STCBMF16.0 | 16MHz THT | Y2
KPT-2012SGC | LED GREEN - SMD-0805 | ON
KPT-2012YC | LED YELLOW - SMD - 0805 | L, RX, TX
LD1117S50CTR | Low-dropout linear regulator 5V -LM1117IMPX-5.0 | IC1
LMV358IDGKR | Dual low-voltage (2.7 V to 5.5 V), operational amplifiers with rail-to-rail output swing LMV358IDGKR | IC7
LP2985-33DBVR | 150-mA LOW-NOISE LOW-DROPOUT REGULATOR WITH SHUTDOWN LP2985-33DBVR | IC6
MF-MSMF050-2 | 500 mA Multifuse ï¿½ Polyfuse | F1
MH2029-300Y | BLM21 | L1
PJ-102AH |  | X1
PMV48XP,215 | 20 V, 3.5 A P-channel Trench MOSFET - PMV48XP | T1
SD1206S100S1R0 | small-signal high-speed Switching Diodes CD1206 | D2, D3
TSW-107-06-T-D | PIN HEADER | JP5
TSW-107-06-T-D | 18x2 F V h 8,5 p2,54 | XIO
TSW-107-06-T-D | Female Connector strip for Arduino bases - 8x1 F V h 8,5 p2,54 serigrafato POWER | POWER
TSW-107-06-T-D | Female Connector strip for Arduino bases - 8x1 F V h 8,5 p2,54mm | ADCL
TSW-107-06-T-D |  | FD1, FD2, FD3, FD4
TSW-107-06-T-D | 3x2 M V h 8,5 mm p2,54 | ICSP, ICSP1
TSW-107-06-T-D | SMD solder JUMPER | GROUND, RESET-EN
USB-B-S-RA-WT-SPCC | USB - B | X2

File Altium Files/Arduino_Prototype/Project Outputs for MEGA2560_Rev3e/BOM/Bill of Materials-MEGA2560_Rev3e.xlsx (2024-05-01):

Name | Designator | Footprint | Manufacturer Part Number 1 | PART_NUMBER
FH254-108DF08500V | ADCL | 1X08 |  | FH254-108DF08500V
22p | C1 | C0603-ROUND |  | 22pF_0603
100nF | C2 | C0603-ROUND |  | cl10b104kbnc
100nF | C3 | C0603-ROUND |  | cl10b104kbnc
100nF | C4 | C0603-ROUND |  | cl10b104kbnc
100nF | C5 | C0603-ROUND |  | cl10b104kbnc
100nF | C6 | C0603-ROUND |  | cl10b104kbnc
100nF | C7 | C0603-ROUND |  | cl10b104kbnc
100nF | C8 | C0603-ROUND |  | cl10b104kbnc
100nF | C9 | C0603-ROUND |  | cl10b104kbnc
1uF | C10 | C0603-ROUND |  | 1uF_0603/GRM188R61E105KA12D
100nF | C11 | C0603-ROUND |  | cl10b104kbnc
100nF | C12 | C0603-ROUND |  | cl10b104kbnc
1uF | C13 | C0603-ROUND |  | 1uF_0603/GRM188R61E105KA12D
22p | C14 | C0603-ROUND |  | 22pF_0603
22p | C15 | C0603-ROUND |  | 22pF_0603
100nF | C16 | C0603-ROUND |  | cl10b104kbnc
M7 | D1 | SMB |  | M7
CD1206-S01575 | D2 | MINIMELF |  | CD1206-S01575
CD1206-S01575 | D3 | MINIMELF |  | CD1206-S01575
MF-MSMF050-2 500mA | F1 | L1812 |  | MF-MSMF050-2
FIDUCIALMOUNT | FD1 | FIDUCIA-MOUNT
FIDUCIALMOUNT | FD2 | FIDUCIA-MOUNT
FIDUCIALMOUNT | FD3 | FIDUCIA-MOUNT
FIDUCIALMOUNT | FD4 | FIDUCIA-MOUNT
SJ | GROUND | SJ
1870_LD1117S50CTR | IC1 | LINEAR_SOT223 |  | LD1117S50CTR
ATMEGA2560-15AU | IC3 | TQFP100 |  | ATMEGA2560-16AU
ATMEGA16U2-MU | IC4 | MLF32 |  | ATMEGA16U2-MUR
LP2985-33DBVR | IC6 | SOT23-DBV |  | TEXLP2985-33DBVR
LMV358IDGKR | IC7 | MSOP08 |  | LMV358IDGKR
ICSP | ICSP | 2X03 |  | PH254-203DF118A00V
ICSP | ICSP1 | 2X03 |  | PH254-203DF118A00V
2x2M - NM | JP5 | 2X02
Yellow | L | CHIPLED_0805 |  | KPT-2012YC
MH2029-300Y | L1 | 0805 |  | BLM21PG300SN1D_/_MH2029-300Y
10uH | L2 | 0805 |  | CV201210-100K
Green | ON | CHIPLED_0805 |  | KPT-2012SGC
47uF | PC1 | PANASONIC_D |  | 47uF
47uF | PC2 | PANASONIC_D |  | 47uF
FH254-108DF08500V | POWER | 1X08 |  | FH254-108DF08500T21
1M | R1 | R0603-ROUND |  | 0603_1M
1M | R2 | R0603-ROUND |  | 0603_1M
TS42 | RESET | TS42 |  | IT-1157AHNP-160G-G_GTR
SJ | RESET-EN | SJ
22R | RN2 | CAY16 |  | 064R_22R_/_CAY16-220J4LF
1K | RN3 | CAY16 |  | 064R_1K_/_CAY16-102J4LF
1K | RN4 | CAY16 |  | 064R_1K_/_CAY16-102J4LF
10k | RN5 | CAY16 |  | 064R_10K_/_CAY16-103J4LF
Yellow | RX | CHIPLED_0805 |  | KPT-2012YC
PMV48XP | T1 | SOT-23 |  | PMV48XP
Yellow | TX | CHIPLED_0805 |  | KPT-2012YC
POWERSUPPLY_DC21MMX | X1 | POWERSUPPLY_DC-21MM
0056_USB-B-S-RA-WT-SPCC | X2 | PN61729 |  | USB-B-S-RA-WT-SPCC
18x2F-H8.5 | XIO | 2X18 |  | FH254-218DF08500V
CSTCE16M0V53-R0 | Y1 | RESONATOR |  | CSTCE16M0V53-R0
16MHz | Y2 | QS |  | P011052006 16M/FTX16M20S
BRNCG0603MLC-05E | Z1 | CT/CN0603 |  | BRNCG0603MLC-05E
BRNCG0603MLC-05E | Z2 | CT/CN0603 |  | BRNCG0603MLC-05E

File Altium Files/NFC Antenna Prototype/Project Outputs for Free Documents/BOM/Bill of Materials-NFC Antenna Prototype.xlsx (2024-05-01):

Line # | Name | Description | Designator | Revision ID | Revision State | Revision Status | Quantity | Manufacturer 1 | Manufacturer Part Number 1 | Manufacturer Lifecycle 1 | Supplier 1 | Supplier Part Number 1 | Supplier Unit Price 1 | Supplier Subtotal 1
 | 06035C102KAT2A | General Purpose Ceramic Capacitor, 0603, 1nF, 10%, X7R, 15%, 50V | C1, C13 |  | Unknown server |  | 2 | Kyocera AVX | 06035C102KAT2A | Volume Production | Mouser | 581-06035C102K | 0.1 | 0.2
 | C0402C200J5GACTU | CAP CER 20PF 50V 5% NP0 0402 | C2, C12 |  | Unknown server |  | 2 | KEMET | C0402C200J5GACTU | Volume Production | Arrow Electronics | C0402C200J5GACTU | 0.0981 | 0.1962
 | C0402C680J5GACTU | CAP CER 68PF 50V 5% NP0 0402 | C3, C10 |  | Unknown server |  | 2 | Murata | GRM1555C1H680JA01D | Not Recommended for New Design | Mouser | 81-GRM1555C1H680JA1D | 0.018 | 0.18
 | C0603C560J5GACTU | CAP CER 56PF 50V C0G/NP0 0603 | C4, C11 |  | Unknown server |  | 2 | Kyocera AVX | 06035A560JAT2A | Volume Production | Newark | 43T7238 | 0.003 | 0.006
 | C0603C510J5GACTU | CAP CER 51PF 50V 5% NP0 0603 | C5, C14 |  | Unknown server |  | 2 | KEMET | C0603C510J5GACTU | Volume Production | Mouser | 80-C0603C510J5G | 0.15 | 0.3
 | C0603C300J5GACTU | CAP CER 30PF 50V 5% NP0 0603 | C6, C9 |  | Unknown server |  | 2 | KEMET | C0603C300J5GACTU | Volume Production | Mouser | 80-C0603C300J5G | 0.1 | 0.2
 | C0805C474K5RACTU | CAP CER 0.47UF 50V 10% X7R 0805 | C7, C8 |  | Unknown server |  | 2 | KEMET | C0805C474K5RACTU | Volume Production | Newark | 93K6002 | 0.184 | 0.368
 | 865060653010 | 865060653010 Aluminum Electrolytic Capacitor, Polarized, Aluminum (wet), 50V, 20% +Tol, 20% -Tol, 100uF, Surface Mount, 3333 | C15 |  | Unknown server |  | 1 | Wurth Electronics | 865060653010 | Volume Production | Mouser | 710-865060653010 | 0.68 | 0.68
 | C0603C120J5GACTU | Ceramic Capacitor 12Pf 50V, C0G, 5%, 0603, Full Reel | C16, C17 |  | Unknown server |  | 2 | KEMET | C0603C120J5GACTU | Volume Production | Digi-Key | 399-C0603C120J5GAC7867CT-ND | 0.1 | 0.2
 | C0402C104K8PACTU | CAP CER 0.1UF 10V X5R 0402 | C18, C21, C23 |  | Unknown server |  | 3 | KEMET | C0402C104K8PACTU | Volume Production | Newark | 78H4791 | 0.007 | 0.021
 | C1206C105K5RACTU | Chip Capacitor, 1 uF, +/- 10%, 50 V, -55 to 125 degC, 1206 (3216 Metric), RoHS, Tape and Reel | C19, C20 |  | Unknown server |  | 2 | KEMET | C1206C105K5RACTU | Volume Production | Mouser | 80-C1206C105K5R | 0.24 | 0.48
 | C4532X7R1H685K250KB | Multilayer Ceramic Capacitors 6.8uF ±10% 50V X7R SMD 1812 | C22 |  | Unknown server |  | 1 | TDK | C4532X7R1H685K250KB | Volume Production | Newark | 13T1119 | 1.04 | 1.04
 | 22-28-4050 | 22-28-4050 KK® 254 Breakaway Header, Vertical, 5 Circuits, Tin (Sn) Plating, Mating Pin Length 6.09mm | J1 |  | Unknown server |  | 1 | Molex | 22-28-4050 | Volume Production | Arrow Electronics | 22-28-4050 | 0.0952 | 0.0952
 | IHLP2020CZERR47M01 | Fixed Inductors Commercial High Saturation Series 0.47uH 12.2A 7.04mΩ 20% | L1, L2 |  | Unknown server |  | 2 | Vishay Dale | IHLP2020CZERR47M01 | Volume Production | Mouser | 70-IHLP2020CZERR47M0 | 1.08 | 2.16
 | LQW18AN22NG00D | Wire Wound RF Inductor 22nH ±2% 500mA 0.17Ω 0603 (1608) | L3 |  | Unknown server |  | 1 | Murata | LQW18AN22NG00D | Volume Production | Mouser | 81-LQW18AN22NG00D | 0.15 | 0.15
 | 61301011021 |  | P1 |  | Unknown server |  | 1 | Wurth Electronics | 61301011021 | Volume Production | Mouser | 710-61301011021 | 1.27 | 1.27
 | RC0805FR-071KL | Chip Resistor, 1 KOhm, +/- 1%, 125 mW, -55 to 155 degC, 0805 (2012 Metric), RoHS, Tape and Reel | R1, R6 |  | Unknown server |  | 2 | Yageo | RC0805FR-071KL | Volume Production | Mouser | 603-RC0805FR-071KL | 0.016 | 0.16
 | RT1206BRD0712KL | RES SMD 12K OHM 0.1% 1/4W 1206 | R2, R5 |  | Unknown server |  | 2 | Yageo | RT1206BRD0712KL | Volume Production | Digi-Key | 13-RT1206BRD0712KLCT-ND | 0.63 | 1.26
 | CRCW060315R0FKEA | RES Thick Film, 15Ω, 1%, 0.1W, 100ppm/°C, 0603 | R3, R4 |  | Unknown server |  | 2 | Vishay | CRCW060315R0FKEA | Volume Production | Newark | 42K3723 | 0.003 | 0.006
 | RC0603JR-070RL | Chip Resistor, 0 Ohm, +/- 5%, 0.1 W, -55 to 155 degC, 0603 (1608 Metric), RoHS, Tape and Reel | R7, R8, R10, R13, R15, R16, R17, R18 |  | Unknown server |  | 8 | Yageo | RC0603JR-070RL | Volume Production | Mouser | 603-RC0603JR-070RL | 0.009 | 0.09
 | RK73B1JTTD472J |  | R9, R11, R14 |  | Unknown server |  | 3 | KOA Speer | RK73B1JTTD472J | Volume Production | Mouser | 660-RK73B1JTTD472J | 0.01 | 0.1
 | RC1206FR-071KL | Chip Resistor, 1 KOhm, +/- 1%, 0.25 W, -55 to 155 degC, 1206 (3216 Metric), RoHS, Tape and Reel | R12 |  | Unknown server |  | 1 | Yageo | RC1206FR-071KL | Volume Production | Digi-Key | 311-1.00KFRCT-ND | 0.1 | 0.1
 | CLRC66302HN,118 | Telecom Circuit, 1-Func, CMOS, PQCC32 | U1 |  | Not managed |  | 1 | NXP Semiconductors | CLRC66302HN,118 | Not Recommended for New Design | Digi-Key | 568-13922-1-ND | 10.72 | 10.72
 | LFXTAL036075BULK | Parallel - Fundamental Quartz Crystal, 27.12MHz Nom | X1 |  | Not managed |  | 1

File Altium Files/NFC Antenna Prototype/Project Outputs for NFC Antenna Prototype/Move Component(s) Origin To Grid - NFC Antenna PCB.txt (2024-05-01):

Move Component(s) Origin to Grid
Filename     : C:\Users\Alex\My Drive\School\Classes\Capstone 1\Altium Designer Projects\NFC Antenna Prototype\NFC Antenna PCB.PcbDoc
Date         : 12/10/2023
Time         : 7:18:45 PM
Time Elapsed : 00:00:00

    Small Component X1-LFXTAL036075BULK (3300mil,4300mil) on Top Layer - Component origin is already ON grid. - Component pads are OFF grid. No action taken.
    LCC Component U1-CLRC66302HN,118 (2700mil,4150mil) on Top Layer - Component origin is already ON grid. - Component pads are OFF grid. No action taken.
    SMT Small Component R18-RC0603JR-070RL (2900mil,4450mil) on Top Layer - Component origin is already ON grid. - Component pads are OFF grid. No action taken.
    SMT Small Component R17-RC0603JR-070RL (2800mil,4450mil) on Top Layer - Component origin is already ON grid. - Component pads are OFF grid. No action taken.
    SMT Small Component R16-RC0603JR-070RL (2700mil,4450mil) on Top Layer - Component origin is already ON grid. - Component pads are OFF grid. No action taken.
    SMT Small Component R15-RC0603JR-070RL (2600mil,4450mil) on Top Layer - Component origin is already ON grid. - Component pads are OFF grid. No action taken.
    SMT Small Component R14-RK73B1JTTD472J (2400mil,4450mil) on Top Layer - Component origin is already ON grid. - Component pads are OFF grid. No action taken.
    SMT Small Component R13-RC0603JR-070RL (2500mil,4450mil) on Top Layer - Component origin is already ON grid. - Component pads are OFF grid. No action taken.
    SMT Small Component R12-RC1206FR-071KL (2300mil,4400mil) on Top Layer - Component origin is already ON grid. - Component pads are OFF grid. No action taken.
    SMT Small Component R11-RK73B1JTTD472J (2475mil,4250mil) on Top Layer - Component origin is already ON grid. - Component pads are OFF grid. No action taken.
    SMT Small Component R10-RC0603JR-070RL (2175mil,4250mil) on Top Layer - Component origin is already ON grid. - Component pads are OFF grid. No action taken.
    SMT Small Component R9-RK73B1JTTD472J (2925mil,4300mil) on Top Layer - Component origin is already ON grid. - Component pads are OFF grid. No action taken.
    SMT Small Component R8-RC0603JR-070RL (2925mil,4150mil) on Top Layer - Component origin is already ON grid. - Component pads are OFF grid. No action taken.
    SMT Small Component R7-RC0603JR-070RL (3100mil,4475mil) on Top Layer - Component origin is already ON grid. - Component pads are OFF grid. No action taken.
    SMT Small Component R6-RC0805FR-071KL (2350mil,3750mil) on Top Layer - Component origin is already ON grid. - Component pads are OFF grid. No action taken.
    SMT Small Component R5-RT1206BRD0712KL (2100mil,3600mil) on Top Layer - Component origin is already ON grid. - Component pads are OFF grid. No action taken.
    SMT Small Component R4-CRCW060315R0FKEA (1800mil,3300mil) on Top Layer - Component origin is already ON grid. - Component pads are OFF grid. No action taken.
    SMT Small Component R3-CRCW060315R0FKEA (2750mil,3250mil) on Top Layer - Component origin is already ON grid. - Component pads are OFF grid. No action taken.
    SMT Small Component R2-RT1206BRD0712KL (3025mil,3450mil) on Top Layer - Component origin is already ON grid. - Component pads are OFF grid. No action taken.
    SMT Small Component R1-RC0805FR-071KL (3000mil,3900mil) on Top Layer - Component origin is already ON grid. - Component pads are OFF grid. No action taken.
    SIP Component P1-61301011021 (2375mil,4975mil) on Top Layer - Component origin is already ON grid. - Component pads are OFF grid. No action taken.
    SMT Small Component L3-LQW18AN22NG00D (1550mil,4625mil) on Top Layer - Component origin is already ON grid. - Component pads are OFF grid. No action taken.
    SMT Small Component L2-IHLP2020CZERR47M01 (2100mil,3850mil) on Top Layer - Component origin is already ON grid. - Component pads are OFF grid. No action taken.
    SMT Small Component L1-IHLP2020CZERR47M01 (2800mil,3650mil) on Top Layer - Component origin is already ON grid. - Component pads are OFF grid. No action taken.
    SIP Component J1-22-28-4050 (1525mil,3900mil) on Top Layer - Component origin is already ON grid.
    SMT Small Component C23-C0402C104K8PACTU (2750mil,3925mil) on Top Layer - Component origin is already ON grid. - Component pads are OFF grid. No action taken.
    SMT Small Component C22-C4532X7R1H685K250KB (1500mil,4350mil) on Top Layer - Component origin is already ON grid. - Component pads are OFF grid. No action taken.
    SMT Small Component C21-C0402C104K8PACTU (1500mil,4500mil) on Top Layer - Component origin is already ON grid. - Component pads are OFF grid. No action taken.
    SMT Small Component C20-C1206C105K5RACTU (3000mil,4450mil) on Top Layer - Component origin is already ON grid. - Component pads are OFF grid. No action taken.
    SMT Small Component C19-C1206C105K5RACTU (2150mil,4400mil) on Top Layer - Component origin is already ON grid. - Component pads are OFF grid. No action taken.
    SMT Small Component C18-C0402C104K8PACTU (1450mil,4625mil) on Top Layer - Component origin is already ON grid. - Component pads are OFF grid. No action taken.
    SMT Small Component C17-C0603C120J5GACTU (3075mil,4050mil) on Top Layer - Component origin is already ON grid. - Component pads are OFF grid. No action taken.
    SMT Small Component C16-C0603C120J5GACTU (3125mil,4350mil) on Top Layer - Component origin is already ON grid. - Component pads are OFF grid. No action taken.
    SMT Small Component C15-865060653010 (1800mil,4450mil) on Top Layer - Component origin is already ON grid. - Component pads are OFF grid. No action taken.
    SMT Small Component C14-C0603C510J5GACTU (1800mil,3475mil) on Top Layer - Component origin is already ON grid. - Component pads are OFF grid. No action taken.
    SMT Small Component C13-06035C102KAT2A (2325mil,3600mil) on Top Layer - Component origin is already ON grid. - Component pads are OFF grid. No action taken.
    SMT Small Component C12-C0402C200J5GACTU (1900mil,3475mil) on Top Layer - Component origin is already ON grid. - Component pads are OFF grid. No action taken.
    SMT Small Component C11-C0603C560J5GACTU (1900mil,3625mil) on Top Layer - Component origin is already ON grid. - Component pads are OFF grid. No action taken.
    SMT Small Component C10-C0402C680J5GACTU (1800mil,3625mil) on Top Layer - Component origin is already ON grid. - Component pads are OFF grid. No action taken.
    SMT Small Component C9-C0603C300J5GACTU (1950mil,3275mil) on Top Layer - Component origin is already ON grid. - Component pads are OFF grid. No action taken.
    SMT Small Component C8-C0805C474K5RACTU (2575mil,3900mil) on Top Layer - Component origin is already ON grid. - Component pads are OFF grid. No action taken.
    SMT Small Component C7-C0805C474K5RACTU (2400mil,4000mil) on Top Layer - Component origin is already ON grid. - Component pads are OFF grid. No action taken.
    SMT Small Component C6-C0603C300J5GACTU (2600mil,3225mil) on Top Layer - Component origin is already ON grid. - Component pads are OFF grid. No action taken.
    SMT Small Component C5-C0603C510J5GACTU (2725mil,3450mil) on Top Layer - Component origin is already ON grid. - Component pads are OFF grid. No action taken.
    SMT Small Component C4-C0603C560J5GACTU (2575mil,3350mil) on Top Layer - Component origin is already ON grid. - Component pads are OFF grid. No action taken.
    SMT Small Component C3-C0402C680J5GACTU (2600mil,3450mil) on Top Layer - Component origin is already ON grid. - Component pads are OFF grid. No action taken.
    SMT Small Component C2-C0402C200J5GACTU (2725mil,3350mil) on Top Layer - Component origin is already ON grid. - Component pads are OFF grid. No action taken.
    SMT Small Component C1-06035C102KAT2A (3050mil,3625mil) on Top Layer - Component origin is already ON grid. - Component pads are OFF grid. No action taken.
count : 48

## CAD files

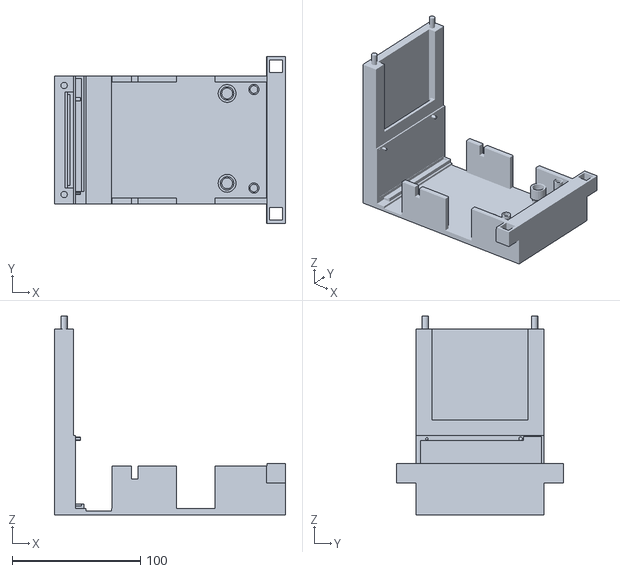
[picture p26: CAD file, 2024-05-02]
3D Models/CEE410-Shelf Middle (Print)-0713453.stl
180.0 x 130.0 x 155.0

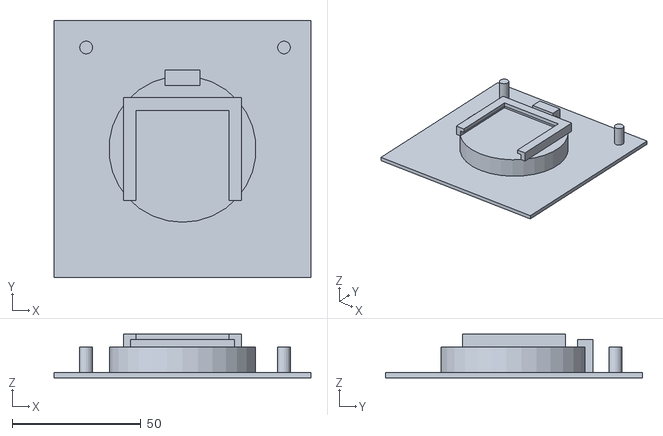
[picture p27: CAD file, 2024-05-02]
3D Models/CEE410-Panel Cover-0713453.stl
100.0 x 100.0 x 17.0

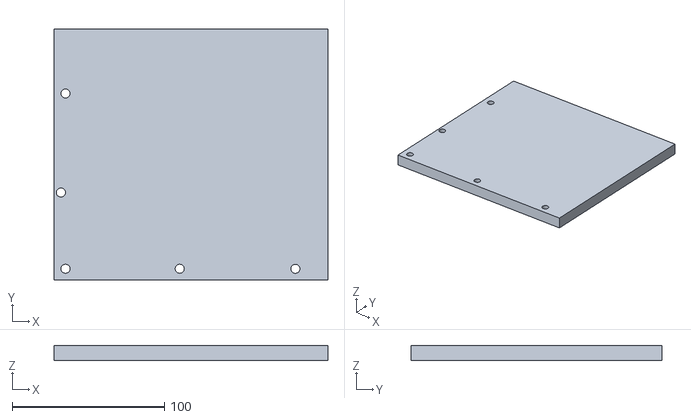
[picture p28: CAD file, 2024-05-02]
3D Models/CEE410-Shelf Top-0713453.stl
180.0 x 165.0 x 10.0

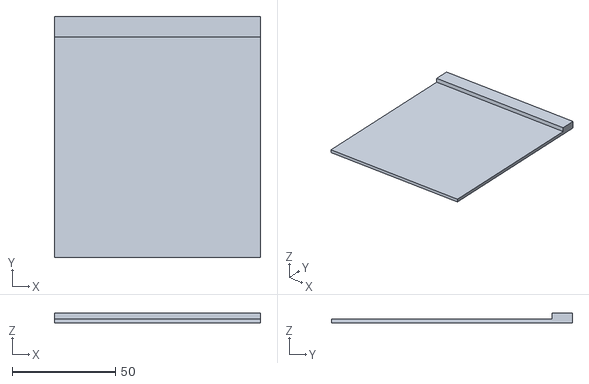
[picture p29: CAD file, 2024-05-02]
3D Models/CEE410-Screen Edge-0713453.stl
100.0 x 117.0 x 4.75

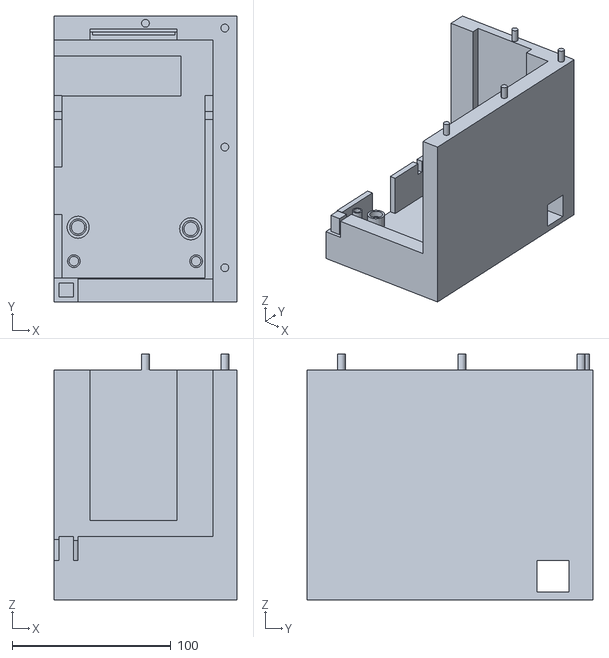
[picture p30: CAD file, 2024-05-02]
3D Models/CEE410-Shelf Right (print)-0713453.stl
115.0 x 180.0 x 155.0

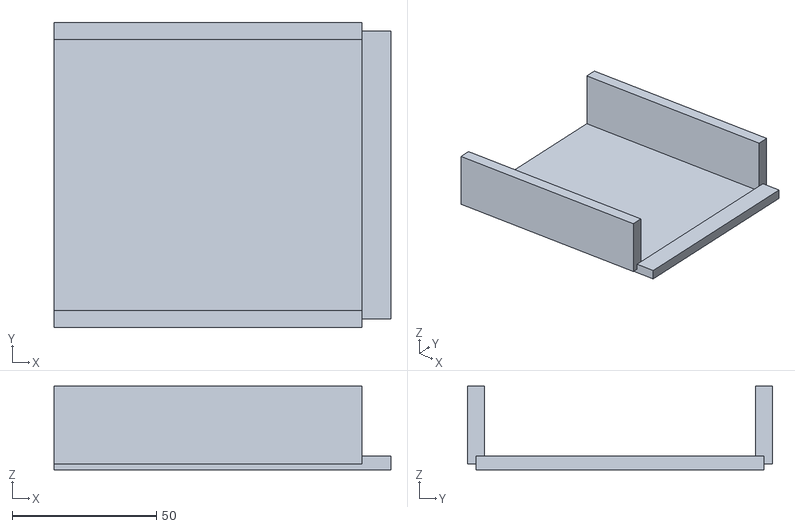
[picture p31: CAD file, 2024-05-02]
3D Models/CEE410-Screens (M)-0713453.stl
117.0 x 106.0 x 29.0

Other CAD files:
3D Models/CEE410-Shelf Left (Print)-0713453.stl

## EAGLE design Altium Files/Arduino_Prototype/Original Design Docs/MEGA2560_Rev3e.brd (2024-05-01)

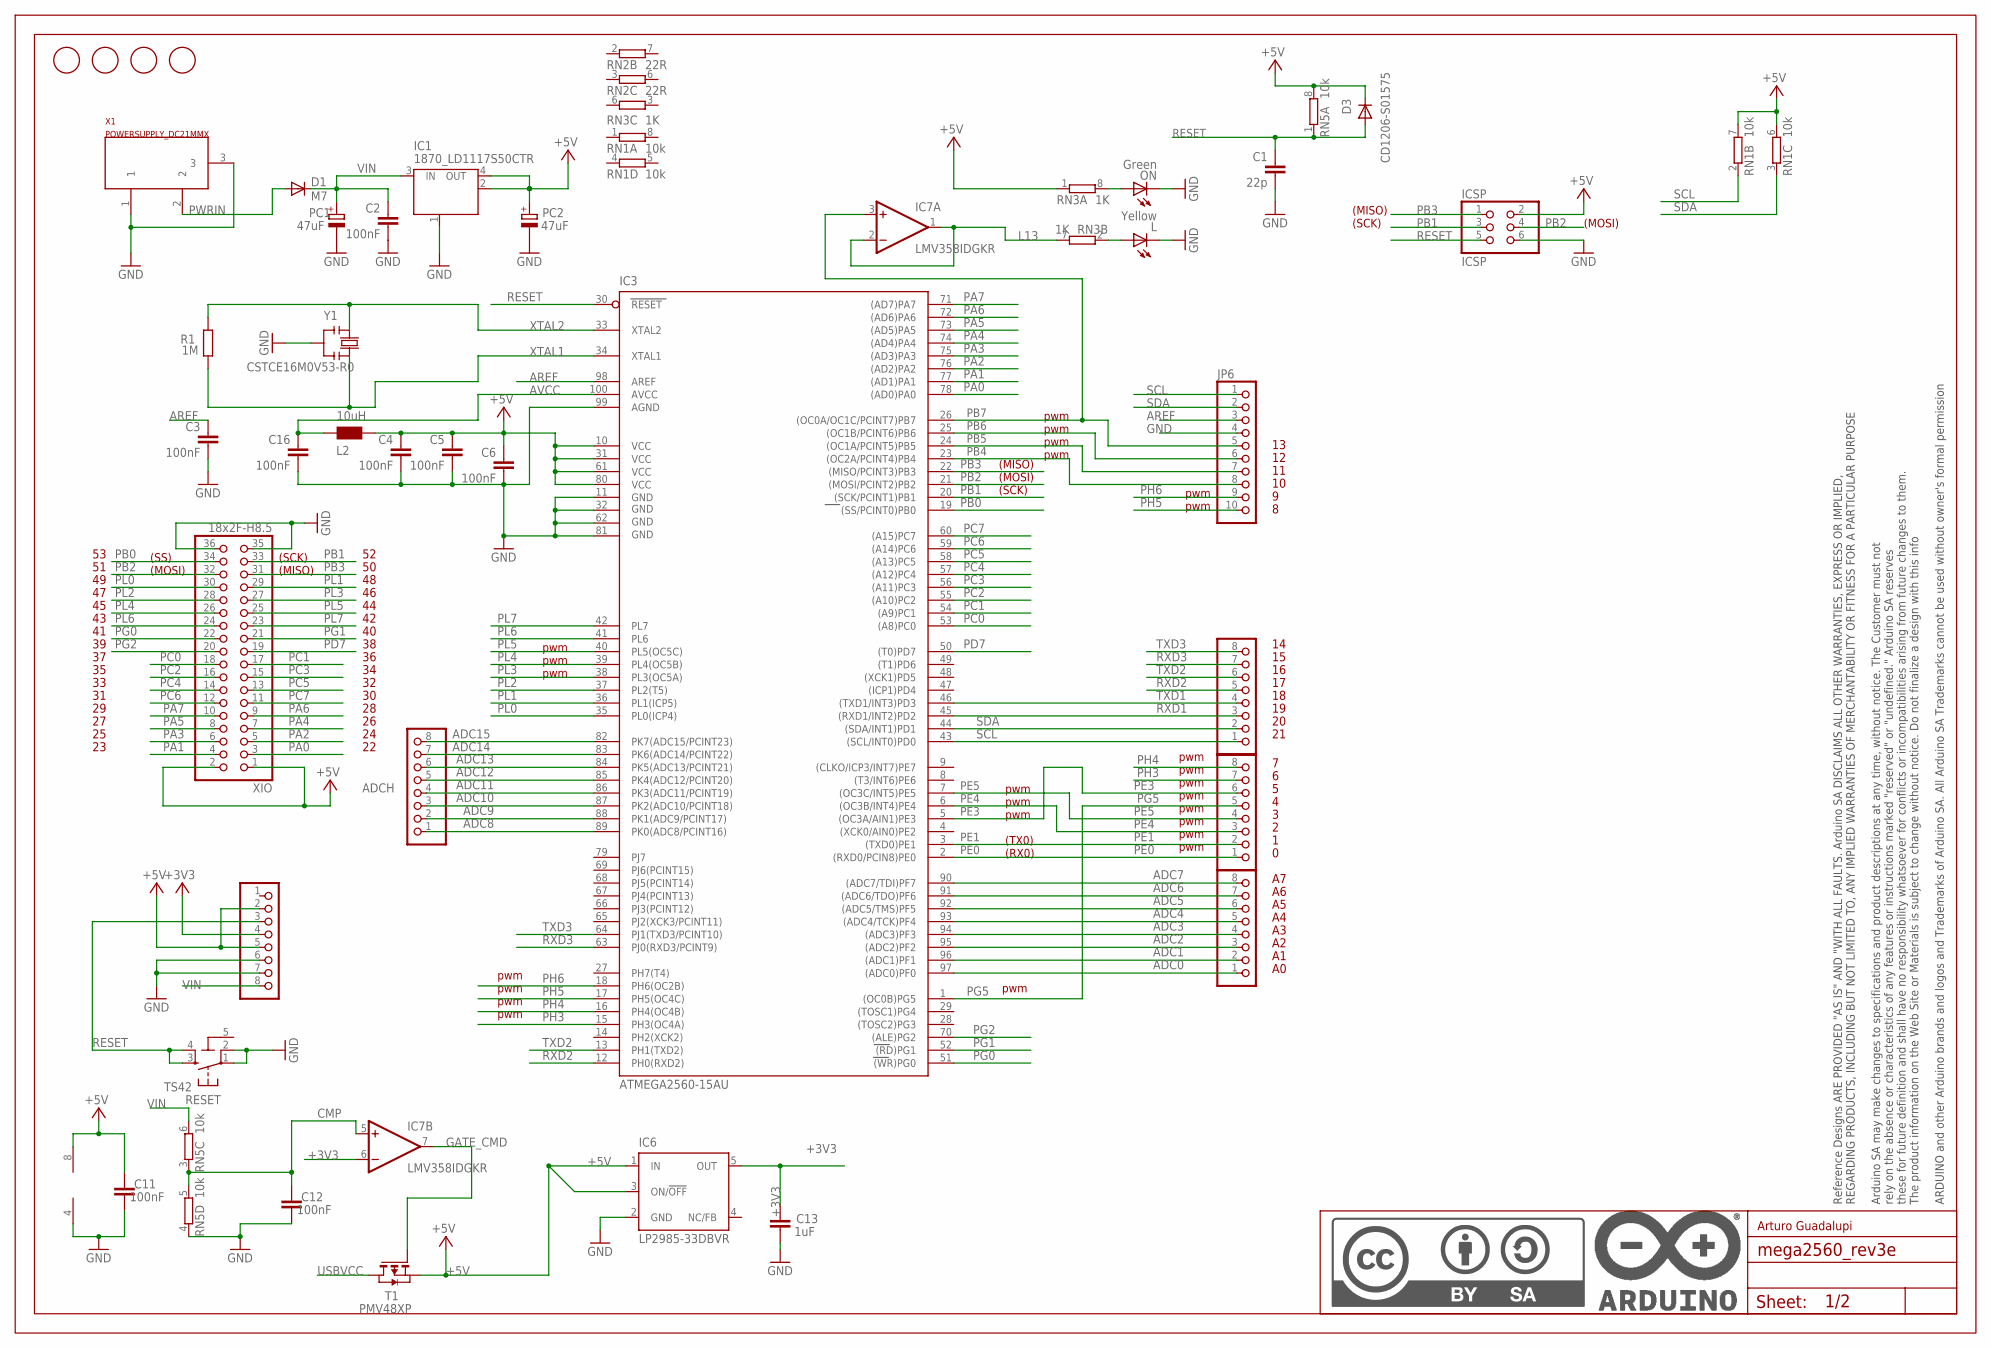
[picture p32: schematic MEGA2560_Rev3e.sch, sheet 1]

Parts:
ADCH: FH254-108DF08500V; 1X08
ADCL: FH254-108DF08500V; 1X08
C1: 22p; C0603-ROUND
C2, C3, C4, C5, C6, C11, C12, C16: 100nF; C0603-ROUND
C13: 1uF; C0603-ROUND
COMMUNICATION: FH254-108DF08500V; 1X08
D1: M7; SMB
D3: CD1206-S01575; MINIMELF
FD1, FD2, FD3, FD4: FIDUCIALMOUNT; FIDUCIA-MOUNT
IC1: 1870_LD1117S50CTR; LINEAR_SOT223
IC3: ATMEGA2560-15AU; TQFP100
IC6: LP2985-33DBVR; SOT23-DBV
IC7: LMV358IDGKR; MSOP08
ICSP: ICSP; 2X03
JP6: FH254-110DF08500V; 1X10
L: Yellow; CHIPLED_0805
L2: 10uH; 0805
ON: Green; CHIPLED_0805
PC1, PC2: 47uF; PANASONIC_D
POWER: FH254-108DF08500V; 1X08
PWML: FH254-108DF08500V; 1X08
R1: 1M; R0603-ROUND
RESET: TS42
RN1, RN5: 10k; CAY16
RN2: 22R; CAY16
RN3: 1K; CAY16
T1: PMV48XP; SOT-23; PART_NUMBER PMV48XP
U$1: DNP; FRAME
X1: POWERSUPPLY_DC21MMX; POWERSUPPLY_DC-21MM
XIO: 18x2F-H8.5; 2X18
Y1: CSTCE16M0V53-R0; RESONATOR

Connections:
5-GND: RESET.5 (5-GND)
+3V3: C13.2, IC6.5 (OUT), IC7.6 (-IN), POWER.4
+5V: C4.1, C5.1, C6.1, C11.2, D3.C, IC1.2 (OUT), IC1.4 (OUT), IC3.10 (VCC), IC3.31 (VCC1), IC3.61 (VCC2), IC3.80 (VCC3), IC6.1 (IN), IC6.3 (ON/!OFF), IC7.8 (V+), ICSP.2, L2.2, PC2.+, POWER.2, POWER.5, RN1.6 (2), RN1.7 (2), RN3.1, RN5.8 (2), T1.2 (S), XIO.1, XIO.2; also elsewhere on the board
ADC0: ADCL.1, IC3.97 ((ADC0)PF0)
ADC1: ADCL.2, IC3.96 ((ADC1)PF1)
ADC2: ADCL.3, IC3.95 ((ADC2)PF2)
ADC3: ADCL.4, IC3.94 ((ADC3)PF3)
ADC4: ADCL.5, IC3.93 ((ADC4/TCK)PF4)
ADC5: ADCL.6, IC3.92 ((ADC5/TMS)PF5)
ADC6: ADCL.7, IC3.91 ((ADC6/TDO)PF6)
ADC7: ADCL.8, IC3.90 ((ADC7/TDI)PF7)
ADC8: ADCH.1, IC3.89 (PK0(ADC8/PCINT16))
ADC9: ADCH.2, IC3.88 (PK1(ADC9/PCINT17))
ADC10: ADCH.3, IC3.87 (PK2(ADC10/PCINT18))
ADC11: ADCH.4, IC3.86 (PK3(ADC11/PCINT19))
ADC12: ADCH.5, IC3.85 (PK4(ADC12/PCINT20))
ADC13: ADCH.6, IC3.84 (PK5(ADC13/PCINT21))
ADC14: ADCH.7, IC3.83 (PK6(ADC14/PCINT22))
ADC15: ADCH.8, IC3.82 (PK7(ADC15/PCINT23))
AREF: C3.1, IC3.98 (AREF), JP6.3
AVCC: C16.1, IC3.100 (AVCC), L2.1
CMP: C12.2, IC7.5 (+IN), RN5.3 (1), RN5.5 (2)
GATE_CMD: IC7.7 (OUT), T1.3 (G)
GND: C1.2, C2.2, C3.2, C4.2, C5.2, C6.2, C11.1, C12.1, C13.1, C16.2, IC1.1 (GND/ADJ), IC3.11 (GND), IC3.32 (GND1), IC3.62 (GND2), IC3.81 (GND3), IC3.99 (AGND), IC6.2 (GND), IC7.4 (V-), ICSP.6, JP6.4, L.C, ON.C, PC1.-, PC2.-, POWER.6, POWER.7, RESET.1, RESET.2, RN5.4 (1), X1.1, X1.3, XIO.35, XIO.36, Y1.2; also elsewhere on the board
L13: IC7.1 (OUT), IC7.2 (-IN), RN3.7 (2)
unnamed: L.A, RN3.2 (1)
unnamed: ON.A, RN3.8 (2)
PA0: IC3.78 ((AD0)PA0), XIO.3
PA1: IC3.77 ((AD1)PA1), XIO.4
PA2: IC3.76 ((AD2)PA2), XIO.5
PA3: IC3.75 ((AD3)PA3), XIO.6
PA4: IC3.74 ((AD4)PA4), XIO.7
PA5: IC3.73 ((AD5)PA5), XIO.8
PA6: IC3.72 ((AD6)PA6), XIO.9
PA7: IC3.71 ((AD7)PA7), XIO.10
PB0: IC3.19 ((SS/PCINT0)PB0), XIO.34
PB1: IC3.20 ((SCK/PCINT1)PB1), ICSP.3, XIO.33
PB2: IC3.21 ((MOSI/PCINT2)PB2), ICSP.4, XIO.32
PB3: IC3.22 ((MISO/PCINT3)PB3), ICSP.1, XIO.31
PB4: IC3.23 ((OC2A/PCINT4)PB4), JP6.8
PB5: IC3.24 ((OC1A/PCINT5)PB5), JP6.7
PB6: IC3.25 ((OC1B/PCINT6)PB6), JP6.6
PB7: IC3.26 ((OC0A/OC1C/PCINT7)PB7), IC7.3 (+IN), JP6.5
PC0: IC3.53 ((A8)PC0), XIO.18
PC1: IC3.54 ((A9)PC1), XIO.17
PC2: IC3.55 ((A10)PC2), XIO.16
PC3: IC3.56 ((A11)PC3), XIO.15
PC4: IC3.57 ((A12)PC4), XIO.14
PC5: IC3.58 ((A13)PC5), XIO.13
PC6: IC3.59 ((A14)PC6), XIO.12
PC7: IC3.60 ((A15)PC7), XIO.11
PD7: IC3.50 ((T0)PD7), XIO.19
PE0: IC3.2 ((RXD0/PCIN8)PE0), PWML.1; also elsewhere on the board
PE1: IC3.3 ((TXD0)PE1), PWML.2; also elsewhere on the board
PE3: IC3.5 ((OC3A/AIN1)PE3), PWML.6
PE4: IC3.6 ((OC3B/INT4)PE4), PWML.3
PE5: IC3.7 ((OC3C/INT5)PE5), PWML.4
PG0: IC3.51 ((WR)PG0), XIO.22
PG1: IC3.52 ((RD)PG1), XIO.21
PG2: IC3.70 ((ALE)PG2), XIO.20
PG5: IC3.1 ((OC0B)PG5), PWML.5
PH3: IC3.15 (PH3(OC4A)), PWML.7
PH4: IC3.16 (PH4(OC4B)), PWML.8
PH5: IC3.17 (PH5(OC4C)), JP6.10
PH6: IC3.18 (PH6(OC2B)), JP6.9
PL0: IC3.35 (PL0(ICP4)), XIO.30
PL1: IC3.36 (PL1(ICP5)), XIO.29
PL2: IC3.37 (PL2(T5)), XIO.28
PL3: IC3.38 (PL3(OC5A)), XIO.27
PL4: IC3.39 (PL4(OC5B)), XIO.26
PL5: IC3.40 (PL5(OC5C)), XIO.25
PL6: IC3.41 (PL6), XIO.24
PL7: IC3.42 (PL7), XIO.23
PWRIN: D1.A, X1.2
RESET: C1.1, D3.A, IC3.30 (RESET), ICSP.5, POWER.3, RESET.3, RESET.4, RN5.1; also elsewhere on the board
RXD1: COMMUNICATION.3, IC3.45 ((RXD1/INT2)PD2)
RXD2: COMMUNICATION.5, IC3.12 (PH0(RXD2))
RXD3: COMMUNICATION.7, IC3.63 (PJ0(RXD3/PCINT9))
SCL: COMMUNICATION.1, IC3.43 ((SCL/INT0)PD0), JP6.1, RN1.2 (1)
SDA: COMMUNICATION.2, IC3.44 ((SDA/INT1)PD1), JP6.2, RN1.3 (1)
TXD1: COMMUNICATION.4, IC3.46 ((TXD1/INT3)PD3)
TXD2: COMMUNICATION.6, IC3.13 (PH1(TXD2))
TXD3: COMMUNICATION.8, IC3.64 (PJ1(TXD3/PCINT10))
USBVCC: T1.1 (D); also elsewhere on the board
VIN: C2.1, D1.C, IC1.3 (IN), PC1.+, POWER.8, RN5.6 (2)
XTAL1: IC3.34 (XTAL1), R1.1, Y1.3
XTAL2: IC3.33 (XTAL2), R1.2, Y1.1

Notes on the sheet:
(SCK)
(MISO)
(MOSI)
pwm
(TX0)
(RX0)
(SS)
Arturo Guadalupi

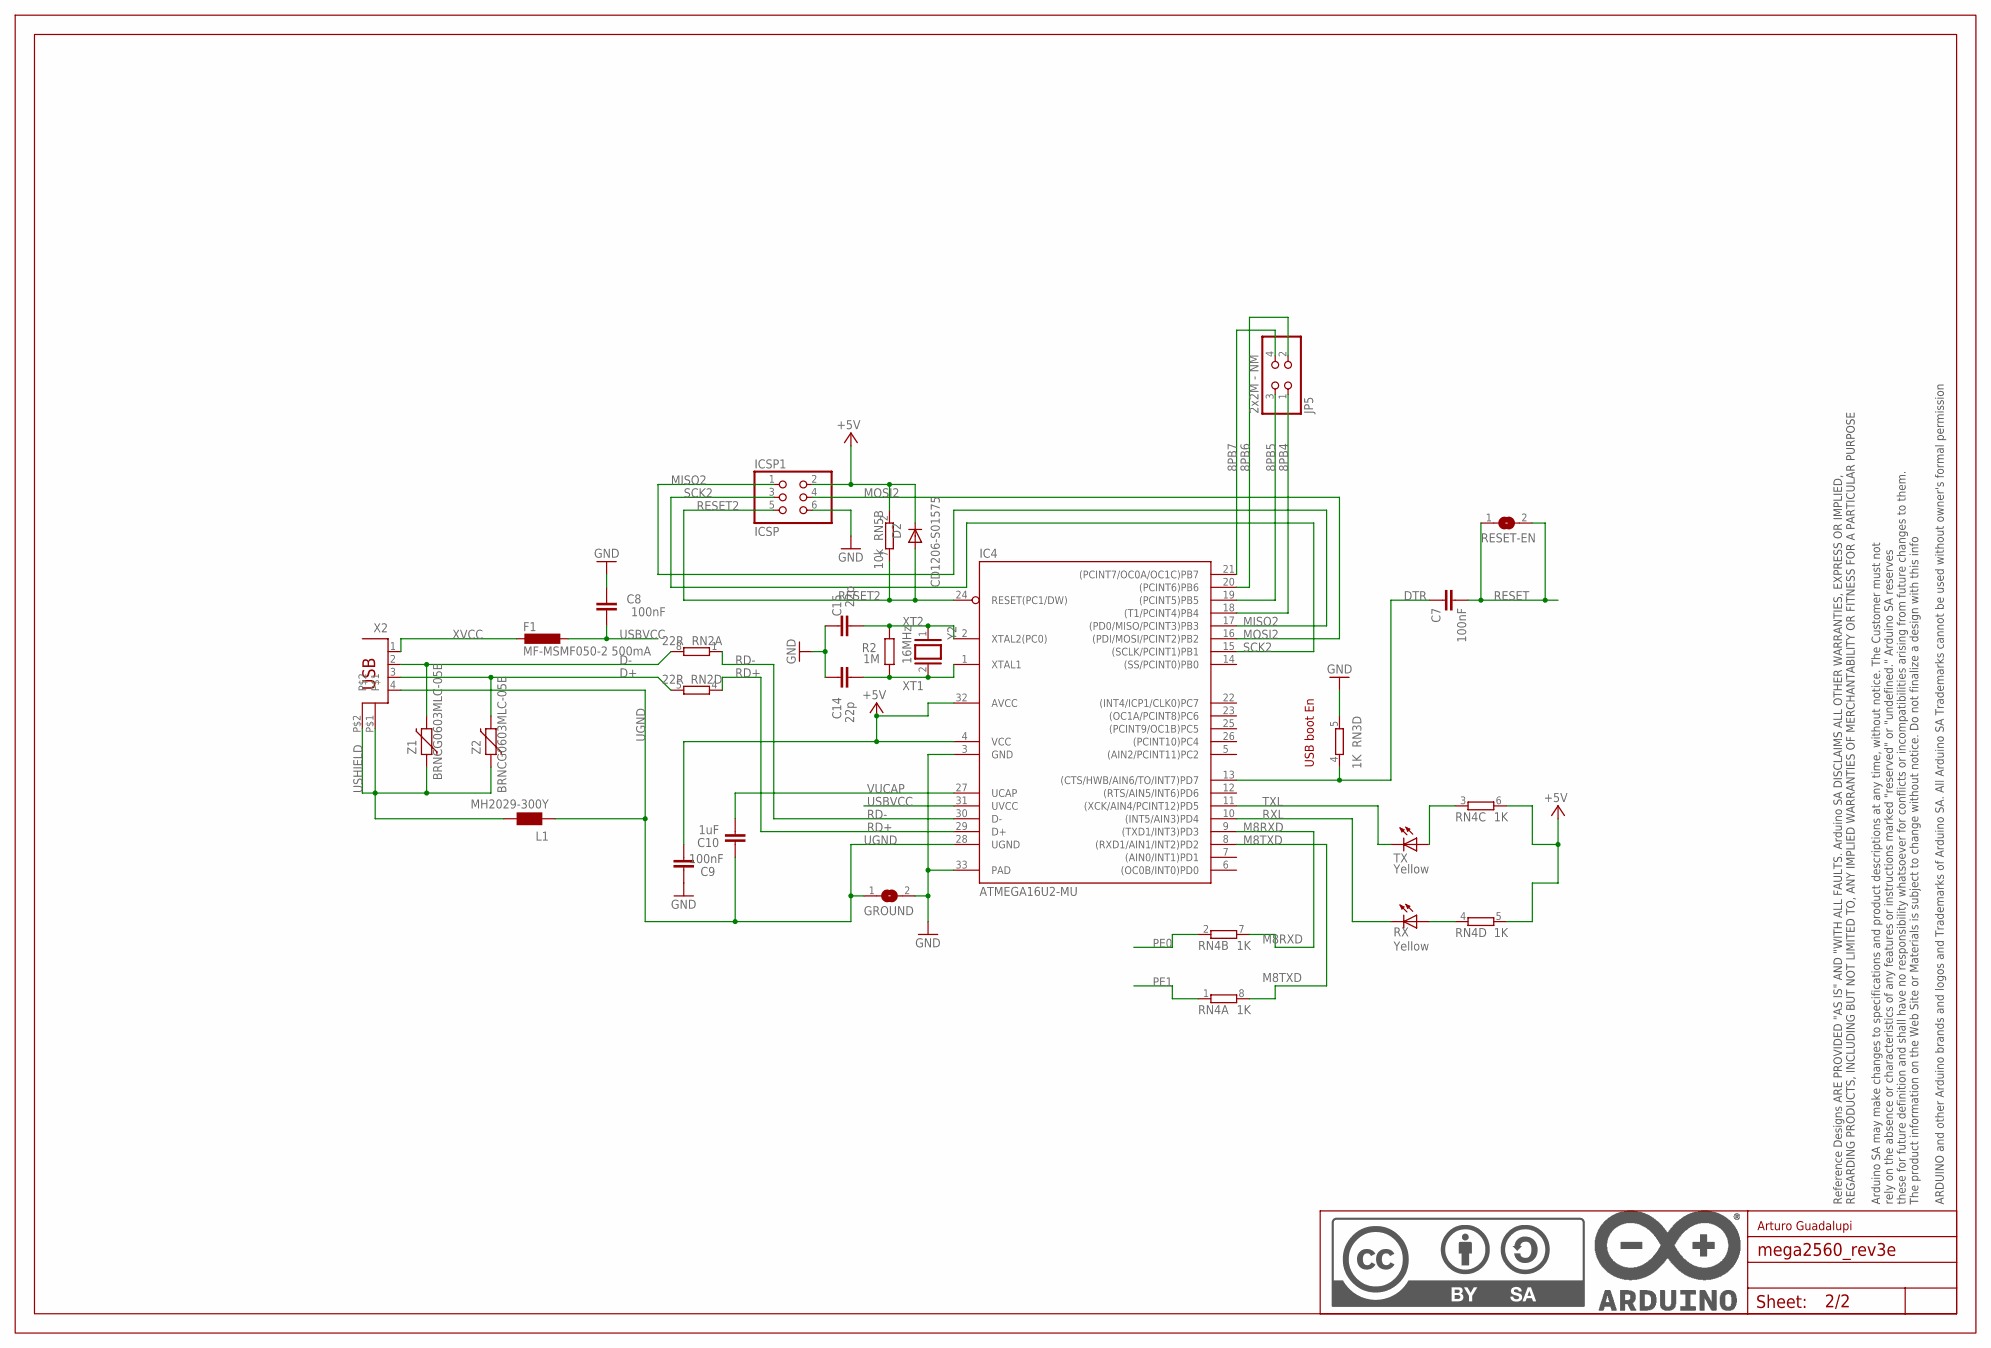
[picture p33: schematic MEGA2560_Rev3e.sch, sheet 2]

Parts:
C7, C8, C9: 100nF; C0603-ROUND
C10: 1uF; C0603-ROUND
C14, C15: 22p; C0603-ROUND
D2: CD1206-S01575; MINIMELF
F1: MF-MSMF050-2 500mA; L1812
GROUND: SJ
IC4: ATMEGA16U2-MU; MLF32
ICSP1: ICSP; 2X03
JP5: 2x2M - NM; 2X02
L1: MH2029-300Y; 0805
R2: 1M; R0603-ROUND
RESET-EN: SJ
RN2: 22R; CAY16
RN3, RN4: 1K; CAY16
RN5: 10k; CAY16
RX: Yellow; CHIPLED_0805
TX: Yellow; CHIPLED_0805
U$2: DNP; FRAME
X2: 0056_USB-B-S-RA-WT-SPCC; PN61729
Y2: 16MHz; QS
Z1, Z2: BRNCG0603MLC-05E; CT/CN0603

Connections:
8PB4: IC4.18 ((T1/PCINT4)PB4), JP5.1
8PB5: IC4.19 ((PCINT5)PB5), JP5.3
8PB6: IC4.20 ((PCINT6)PB6), JP5.2
8PB7: IC4.21 ((PCINT7/OC0A/OC1C)PB7), JP5.4
+5V: C9.1, D2.C, IC4.4 (VCC), IC4.32 (AVCC), ICSP1.2, RN4.5 (2), RN4.6 (2), RN5.2 (1); also elsewhere on the board
D+: RN2.5 (2), X2.3, Z2.2
D-: RN2.8 (2), X2.2, Z1.2
DTR: C7.1, IC4.13 ((CTS/HWB/AIN6/TO/INT7)PD7), RN3.4 (1)
GND: C8.2, C9.2, C14.2, C15.2, GROUND.2, IC4.3 (GND), IC4.33 (PAD), ICSP1.6, RN3.5 (2); also elsewhere on the board
M8RXD: IC4.9 ((TXD1/INT3)PD3), RN4.7 (2)
M8TXD: IC4.8 ((RXD1/AIN1/INT2)PD2), RN4.8 (2)
MISO2: IC4.17 ((PD0/MISO/PCINT3)PB3), ICSP1.1
MOSI2: IC4.16 ((PDI/MOSI/PCINT2)PB2), ICSP1.4
unnamed: RN4.4 (1), RX.A
unnamed: RN4.3 (1), TX.A
PE0: RN4.2 (1); also elsewhere on the board
PE1: RN4.1; also elsewhere on the board
RD+: IC4.29 (D+), RN2.4 (1)
RD-: IC4.30 (D-), RN2.1
RESET: C7.2, RESET-EN.1, RESET-EN.2; also elsewhere on the board
RESET2: D2.A, IC4.24 (RESET(PC1/DW)), ICSP1.5, RN5.7 (2)
RXL: IC4.10 ((INT5/AIN3)PD4), RX.C
SCK2: IC4.15 ((SCLK/PCINT1)PB1), ICSP1.3
TXL: IC4.11 ((XCK/AIN4/PCINT12)PD5), TX.C
UGND: C10.2, GROUND.1, IC4.28 (UGND), L1.1, X2.4
USBVCC: C8.1, F1.1, IC4.31 (UVCC); also elsewhere on the board
USHIELD: L1.2, X2.P$1, X2.P$2, Z1.1, Z2.1
VUCAP: C10.1, IC4.27 (UCAP)
XT1: C14.1, IC4.1 (XTAL1), R2.1, Y2.2
XT2: C15.1, IC4.2 (XTAL2(PC0)), R2.2, Y2.1
XVCC: F1.2, X2.1

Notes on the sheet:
USB boot En
Arturo Guadalupi

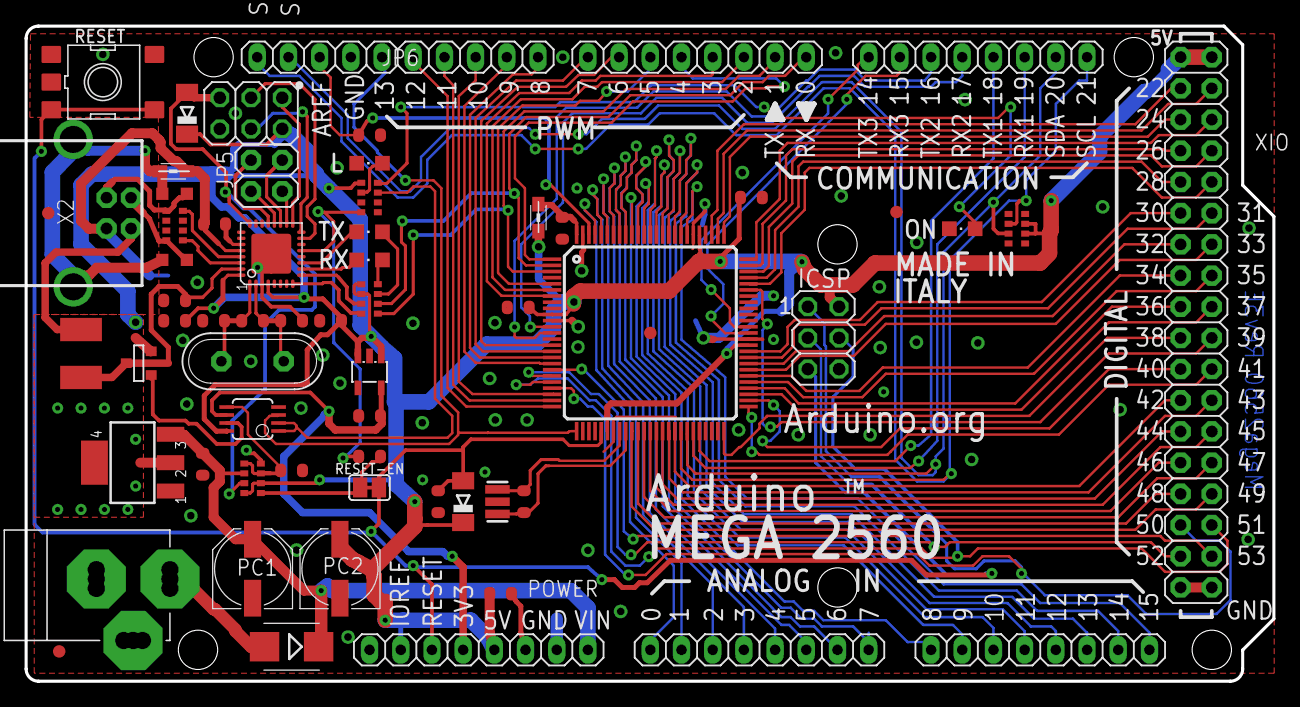
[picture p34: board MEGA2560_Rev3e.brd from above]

Board: 2 copper layers, 101.6 x 53.3 mm, 66 parts (1 on the bottom side), 111 nets.

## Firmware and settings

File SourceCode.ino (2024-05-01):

/*
   Typical pin layout used:
   -----------------------------------------------------------------------------------------
               MFRC522      Arduino       Arduino   Arduino    Arduino          Arduino
               Reader/PCD   Uno/101       Mega      Nano v3    Leonardo/Micro   Pro Micro
   Signal      Pin          Pin           Pin       Pin        Pin              Pin
   -----------------------------------------------------------------------------------------
   RST/Reset   RST          9             5         D9         RESET/ICSP-5     RST
   SPI SS      SDA(SS)      10            53        D10        10               10
   SPI MOSI    MOSI         11 / ICSP-4   51        D11        ICSP-4           16
   SPI MISO    MISO         12 / ICSP-1   50        D12        ICSP-1           14
   SPI SCK     SCK          13 / ICSP-3   52        D13        ICSP-3           15
*/

#include <SPI.h>
#include <MFRC522.h>
#include <Adafruit_NeoPixel.h>

#define UPPER_PAGE 21
#define LOWER_PAGE 22

#define BUTTON_PIN 53

#define PHOTO1_PIN A0
#define PHOTO2_PIN A1
#define PHOTO3_PIN A2

#define MOSI_PIN 51  // static, Blue
#define MISO_PIN 50  // static, Yellow
#define SCK_PIN 52   // static, Green

#define NFC1_RST_PIN 46  // White
#define NFC1_SDA_PIN 49  // Grey

#define NFC2_RST_PIN 45  // Orange
#define NFC2_SDA_PIN 48  // Brown

#define NFC3_RST_PIN 44  // Light Purple
#define NFC3_SDA_PIN 47  // Dark Purple

#define LED_DATA_PIN1 5
#define LED_DATA_PIN2 4
#define LED_DATA_PIN3 3

#define NUM_AMIIBO 97
#define AMIIBO_HEAD 0
#define AMIIBO_TAIL 1
#define AMIIBO_COLOR 2

#define SLOT_FILLED true
#define SLOT_EMPTY false
#define AMIIBO_PLACED 1
#define AMIIBO_REMOVED 2

const long AMIIBO_DATABASE[NUM_AMIIBO][3] = {
  { 0x00000000, 0x00000002, 0xFF3F25 },  //Mario
  { 0x00080000, 0x00030002, 0xFFDD43 },  //Donkey Kong
  { 0x01000000, 0x00040002, 0x00A0DF },  //Link
  { 0x05C00000, 0x00060002, 0x002A8B },  //Samus
  { 0x05C30000, 0x03800002, 0x100097 },  //Dark Samus
  { 0x00030000, 0x00020002, 0x6DFF32 },  //Yoshi
  { 0x1F000000, 0x000A0002, 0xFFD5E2 },  //Kirby
  { 0x05800000, 0x00050002, 0x1077FE },  //Fox
  { 0x19190000, 0x00090002, 0xFEB912 },  //Pikachu
  { 0x00010000, 0x000C0002, 0x3EE800 },  //Luigi
  { 0x22800000, 0x002C0002, 0xFF211C },  //Ness
  { 0x06000000, 0x00120002, 0x6E66FF },  //Captian Falcon
  { 0x19270000, 0x00260002, 0xFA92FE },  //Jigglypuff
  { 0x00020000, 0x00010002, 0xFFBFF7 },  //Peach
  { 0x00130000, 0x037A0002, 0xFFC11D },  //Daisy
  { 0x00050000, 0x00140002, 0x00B863 },  //Bowser
  { 0x078F0000, 0x03810002, 0x9FC9FF },  //Ice Climbers
  { 0x01010100, 0x00170002, 0x4B40FF },  //Shiek
  { 0x01010000, 0x000E0002, 0xFFEBA2 },  //Zelda
  { 0x00000100, 0x00190002, 0xFE5556 },  //Dr. Mario
  { 0x19AC0000, 0x03850002, 0xFDFA00 },  //Pichu
  { 0x05810000, 0x001C0002, 0x47B7FF },  //Falco
  { 0x21000000, 0x000B0002, 0x25BEFF },  //Marth
  { 0x21020000, 0x00290002, 0x45ABFF },  //Lucina
  { 0x01000000, 0x037C0002, 0xAFFF31 },  //Young Link
  { 0x01020100, 0x001B0002, 0x3019FF },  //Ganondorf
  { 0x19960000, 0x023D0002, 0x7C41FF },  //Mewtwo
  { 0x21040000, 0x02520002, 0x53FE12 },  //Roy
  { 0x21080000, 0x03880002, 0x8383FF },  //Chrom
  { 0x07800000, 0x002D0002, 0xFFE035 },  //Mr. Game and Watch
  { 0x1F010000, 0x00270002, 0x0339FF },  //Meta Knight
  { 0x07400000, 0x00100002, 0xA6DAFF },  //Pit
  { 0x07410000, 0x00200002, 0x7F1BFF },  //Dark Pit
  { 0x05C00100, 0x001D0002, 0x0057C4 },  //Zero Suit Samus
  { 0x00070000, 0x001A0002, 0xFFE71E },  //Wario
  { 0x37800000, 0x038A0002, 0x008AFD },  //Snake
  { 0x21010000, 0x00180002, 0xF42200 },  //Ike
  { 0x1D400000, 0x03870002, 0xFFC003 },  //Pokemon Trainer
  { 0x19070000, 0x03840002, 0x8EF1FE },  //Squirtle
  { 0x19020000, 0x03830002, 0x0DFE77 },  //Ivysaur
  { 0x19060000, 0x00240002, 0xFF5F1A },  //Charizard
  { 0x00090000, 0x000D0002, 0xFF3E32 },  //Diddy Kong
  { 0x22810000, 0x02510002, 0xFE5B14 },  //Lucas
  { 0x32000000, 0x00300002, 0x5199FE },  //Sonic
  { 0x1F020000, 0x00280002, 0xFFEA78 },  //King Dedede
  { 0x06400100, 0x001E0002, 0xCAFFA0 },  //Olimar
  { 0x1AC00000, 0x00110002, 0xB5E3FF },  //Lucario
  { 0x07810000, 0x00330002, 0x70BDFF },  //ROB (NES)
  { 0x07810000, 0x002E0002, 0x54BCFF },  //ROB (Famicom)
  { 0x01000100, 0x00160002, 0x74FF70 },  //Toon Link
  { 0x05840000, 0x037E0002, 0xFF9999 },  //Wolf
  { 0x01800000, 0x00080002, 0x2BFF6A },  //Villager
  { 0x34800000, 0x00310002, 0x66CAFF },  //Mega Man
  { 0x34800000, 0x02580002, 0xFFEF66 },  //Mega Man (Gold)
  { 0x07000000, 0x00070002, 0x86FF56 },  //Wii Fit Trainer
  { 0x00040100, 0x00130002, 0x6EFFEB },  //Rosalina and Luma
  { 0x06C00000, 0x000F0002, 0x00EC63 },  //Little Mac
  { 0x1B920000, 0x00250002, 0x005CFB },  //Greninja
  { 0x07C00000, 0x00210002, 0xFF4529 },  //Mii Brawler
  { 0x07C00100, 0x00220002, 0x22D9FF },  //Mii Swordfighter
  { 0x07C00200, 0x00230002, 0xFF9344 },  //Mii Gunner
  { 0x07420000, 0x001F0002, 0x77FFC4 },  //Palutena
  { 0x33400000, 0x00320002, 0xFFB53E },  //Pac-Man
  { 0x21030000, 0x002A0002, 0xD461FF },  //Robin
  { 0x22400000, 0x002B0002, 0xFF3A60 },  //Shulk
  { 0x06400100, 0x001E0002, 0xCAFFA0 },  //Alph
  { 0x00060000, 0x00150002, 0x3CF700 },  //Bowser Jr.
  { 0x07820000, 0x002F0002, 0xC65400 },  //Duck Hunt
  { 0x34C00000, 0x02530002, 0xFF231E },  //Ryu
  { 0x34C10000, 0x03890002, 0xAAE2FF },  //Ken
  { 0x36000000, 0x02590002, 0x00D3AD },  //Cloud
  { 0x36000100, 0x03620002, 0x00AB8C },  //Cloud P2
  { 0x21050000, 0x025A0002, 0x23C4FF },  //Corrin
  { 0x21050100, 0x03630002, 0x09CEFE },  //Corrin P2
  { 0x32400000, 0x025B0002, 0x8982FF },  //Bayonetta
  { 0x32400100, 0x03640002, 0x8871FF },  //Bayonetta P2
  { 0x08000100, 0x03820002, 0xFF1E7A },  //Inkling
  { 0x05C20000, 0x037F0002, 0xB500AD },  //Ridley
  { 0x37C00000, 0x038B0002, 0x840800 },  //Simon
  { 0x37C10000, 0x038C0002, 0x006DDA },  //Richter
  { 0x00C00000, 0x037B0002, 0x6BC200 },  //King K. Rool
  { 0x01810000, 0x037D0002, 0xE0FE52 },  //Isabelle
  { 0x1BD70000, 0x03860002, 0xFFD901 },  //Incineroar
  { 0x00240000, 0x038D0002, 0x00AA82 },  //Piranah Plant
  { 0x3A000000, 0x03A10002, 0xB51100 },  //Joker
  { 0x36400000, 0x03A20002, 0xC9A7FF },  //Hero
  { 0x3B400000, 0x03A30002, 0xFFDE73 },  //Banjo and Kazooie
  { 0x3C800000, 0x03A40002, 0x6EB5FF },  //Terry
  { 0x210B0000, 0x03A50002, 0xAFFFC9 },  //Byleth
  { 0x0A400000, 0x041D0002, 0xD5D583 },  //Min Min
  { 0x3DC00000, 0x04220002, 0x8DBBD9 },  //Steve
  { 0x3DC10000, 0x04230002, 0x8DBBD9 },  //Alex
  { 0x36010000, 0x04210002, 0x246C6C },  //Sephiroth
  { 0x33C00000, 0x04200002, 0x7ED4BC },  //Pyra
  { 0x22410000, 0x041E0002, 0x7ED4BC },  //Mythra
  { 0x22420000, 0x041F0002, 0xA43E37 },  //Kazuya
  { 0x3F000000, 0x042E0002, 0xFCF5F5 },  //Sora
};

class photoresistor {
public:
  int pin;
  int high_threshold;
  int low_threshold;
  bool curr_state;

  photoresistor(int nPin) {
    pinMode(nPin, INPUT);
    curr_state = SLOT_EMPTY;
    pin = nPin;
  };

  void set_threshold() {
    high_threshold = analogRead(pin) * 0.70;
    low_threshold = analogRead(pin) * 0.40;
    Serial.print("Threshold: ");
    Serial.print(low_threshold);
    Serial.print("-");
    Serial.println(high_threshold);
    delay(300);
  }

  int get_slot_state() {
    int val = analogRead(pin);
    if (val < low_threshold) {  // Dark - slot is filled
      if (curr_state == SLOT_FILLED) {
        return 0;
      } else {
        curr_state = SLOT_FILLED;
        return AMIIBO_PLACED;
      }
    } else if (val > high_threshold) {  // Light - slot is not filled
      if (curr_state == SLOT_EMPTY) {
        return 0;
      } else {
        curr_state = SLOT_EMPTY;
        return AMIIBO_REMOVED;
      }
    }
  }
};

photoresistor ph1(PHOTO1_PIN);
photoresistor ph2(PHOTO2_PIN);
photoresistor ph3(PHOTO3_PIN);

MFRC522 board1(NFC1_SDA_PIN, NFC1_RST_PIN);
MFRC522 board2(NFC2_SDA_PIN, NFC2_RST_PIN);
MFRC522 board3(NFC3_SDA_PIN, NFC3_RST_PIN);

Adafruit_NeoPixel pixels1(12, LED_DATA_PIN1, NEO_RGB + NEO_KHZ800);
Adafruit_NeoPixel pixels2(12, LED_DATA_PIN2, NEO_RGB + NEO_KHZ800);
Adafruit_NeoPixel pixels3(12, LED_DATA_PIN3, NEO_RGB + NEO_KHZ800);


void setup() {
  pinMode(NFC1_SDA_PIN, OUTPUT);
  pinMode(NFC2_SDA_PIN, OUTPUT);
  pinMode(NFC3_SDA_PIN, OUTPUT);

  pixels1.begin();
  pixels1.clear();
  pixels2.begin();
  pixels2.clear();
  pixels3.begin();
  pixels3.clear();

  Serial.begin(9600);  // Initialize serial communications with the PC
  while (!Serial)
    ;                                // Do nothing if no serial port is opened (added for Arduinos based on ATMEGA32U4)
  SPI.begin();                       // Init SPI bus
  board1.PCD_Init();                 // Init MFRC522
  board1.PCD_DumpVersionToSerial();  // Show details of PCD - MFRC522 Card Reader details
  board2.PCD_Init();                 // Init MFRC522
  board2.PCD_DumpVersionToSerial();  // Show details of PCD - MFRC522 Card Reader details
  board3.PCD_Init();                 // Init MFRC522
  board3.PCD_DumpVersionToSerial();  // Show details of PCD - MFRC522 Card Reader details
  Serial.println(F("Arduino amiibo reader. Put your NFC-tag to the reader"));

  ph1.set_threshold();
  ph2.set_threshold();
  ph3.set_threshold();
}

long dump_byte_array(byte* buffer, byte bufferSize) {
  long out =
    (buffer[3] * 0x1) + (buffer[2] * 0x100) + (buffer[1] * 0x10000) + (buffer[0] * 0x1000000);
  return out;
}

void set_slot_pixels(int slot, long color) {
  switch (slot) {
    case 0:
      for (int i = 0; i < 4; i++) {
        pixels1.setPixelColor(i, color);
      }
      pixels1.show();
      break;
    case 1:
      for (int i = 0; i < 4; i++) {
        pixels2.setPixelColor(i, color);
      }
      pixels2.show();
      break;
    case 2:
      for (int i = 0; i < 4; i++) {
        pixels3.setPixelColor(i, color);
      }
      pixels3.show();
      break;
  }
}

long get_led_value(long upper, long lower) {
  Serial.println(upper);
  Serial.println(lower);
  for (int i = 0; i < NUM_AMIIBO; i++) {
    if (upper == -1048576 && lower == 2949122){
      Serial.print("worked");
      return AMIIBO_DATABASE[random(0, NUM_AMIIBO)][AMIIBO_COLOR];
    }
    if (AMIIBO_DATABASE[i][AMIIBO_HEAD] == upper /*&& AMIIBO_DATABASE[i][AMIIBO_TAIL] == lower*/) {
      return AMIIBO_DATABASE[i][AMIIBO_COLOR];
    }
  }
  return 0;
}

void get_id(MFRC522 currBoard, int slot) {
  Serial.println("Board Start");
  byte buffer[10];
  byte buffer1_size = 10;
  int i = 0;
  while (i < 50) {
    i++;
    if (!currBoard.PICC_IsNewCardPresent()) {
      //Serial.print("N");
    } else if (!currBoard.PICC_ReadCardSerial()) {
      //Serial.print("L");
    } else {
      byte upper[18];
      byte lower[18];
      byte size = 18;
      currBoard.MIFARE_Read(UPPER_PAGE, upper, &size);
      currBoard.MIFARE_Read(LOWER_PAGE, lower, &size);
      long output = get_led_value(dump_byte_array(upper, 4), dump_byte_array(lower, 4));
      set_slot_pixels(slot, output);
      Serial.print(output, HEX);
      Serial.println();
      currBoard.PICC_HaltA();
      currBoard.PCD_StopCrypto1();
      Serial.println("Board Finish");
    }
  }
}

int num = 0;
void loop() {
  // Select one of the cards

  switch (ph1.get_slot_state()) {
    case AMIIBO_PLACED:
      get_id(board1, 0);
      Serial.println("placed in slot 1");
      break;
    case AMIIBO_REMOVED:
      set_slot_pixels(0, 0);
      Serial.println("removed from slot 1");
      break;
  }


  switch (ph2.get_slot_state()) {
    case AMIIBO_PLACED:
      get_id(board2, 1);
      Serial.println("placed in slot 2");
      break;
    case AMIIBO_REMOVED:
      set_slot_pixels(1, 0);
      Serial.println("removed from slot 2");
      break;
  }

  switch (ph3.get_slot_state()) {
    case AMIIBO_PLACED:
      get_id(board3, 2);
      Serial.println("placed in slot 3");
      break;
    case AMIIBO_REMOVED:
      set_slot_pixels(2, 0);
      Serial.println("removed from slot 3");
      break;
  }
}

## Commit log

2024-05-01 Uploading files
    [Bill of Materials-MEGA2560_Rev3e.xlsx, Bill of Materials-NFC Antenna Prototype.xlsx, Component Schematics.SchDoc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]
2024-05-02 Adding in 3D Models
    [CEE410-Panel Cover-0713453.stl, CEE410-Screen Edge-0713453.stl, CEE410-Screens (M)-0713453.stl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]

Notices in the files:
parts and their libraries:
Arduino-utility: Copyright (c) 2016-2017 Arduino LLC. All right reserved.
